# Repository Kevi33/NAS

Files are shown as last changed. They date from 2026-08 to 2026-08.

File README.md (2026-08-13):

# Parametric Raspberry Pi 5 NAS enclosure

This repository is an executable CadQuery project for a modular, FDM-printable mini-NAS. It is configured for two UGREEN 50422 / US222 drive enclosures, a Raspberry Pi 5 in a provisional GeeekPi metal case, a provisional UGREEN 25851 USB hub, a 120 mm front intake fan, and a measured 140 mm rear exhaust fan.

The build creates real solids rather than a rendering-only mock-up: individual STEP/STL print files, named assembled/exploded/checking STEP models, fit coupons, automated geometry reports, and PNG previews. The individual STL is the manufacturing source of truth: every placed printed instance is hard-gated to reach its final pose by rotation and translation only, never by an assembly-only reflection.

## Current configured envelope

- Body: **146.0 x 291.1 x 174.0 mm** (W x D x H)
- Installed depth including the external rear fan: **326.1 mm**
- External rear fan spacer: **10.0 mm**
- Height including 6 mm feet: **180.0 mm**
- Drive rear cable chamber: **60.0 mm**
- HDD guide clearance: **1.25 mm per guided side**
- HDD-to-HDD airflow gap: **12.0 mm**
- Production joint clearance: **0.20 mm per mating side**, calibrated from the printed P1S fit coupon
- HDD keeper clearance: **0.00 mm per side**, calibrated from the printed retention coupon and isolated from the panel/dovetail setting

The 291.1 mm depth is deliberate. Two 2.8 mm walls, a 25 mm fan, a 6.5 mm fan/drive gap, a 194 mm drive, and a 60 mm cable chamber cannot fit the initial 250-260 mm styling target without sacrificing cable bend space.

The configured printer is a **Bambu Lab P1S** with a physical 256 x 256 x 256 mm build volume. Validation uses a conservative 3 mm XY margin and a 250 mm usable Z limit. The enclosure remains intentionally split and modular; the larger printer profile does not merge or enlarge any enclosure part.

## Install and regenerate

CadQuery 2.6.1 with 64-bit CPython 3.12 is the tested toolchain.

```powershell
python -m venv .venv
.\.venv\Scripts\python.exe -m pip install -r requirements.txt
.\.venv\Scripts\python.exe build.py
```

To generate only the dedicated keeper-retention calibration model without touching enclosure exports, use:

```powershell
.\.venv\Scripts\python.exe build_keeper_retention_test.py
```

To regenerate only the two rear-fan printable parts plus affected assemblies and reports, while hash-protecting every unrelated export and slicer project, use:

```powershell
.\.venv\Scripts\python.exe build_rear_fan_update.py
```

On Linux/macOS, use `.venv/bin/python`. A good run ends with `BUILD RESULT: SUCCESS`; any source-solid, exported-mesh, STEP-reopen, print-bed, collision, cable-route, or service-path failure returns a non-zero exit code. The generator deletes only old files in its known output directories before rebuilding, so renamed artifacts cannot remain stale.

## Generated artifacts

```text
exports/
  individual/
    STL/                  # one printable source part per file
    STEP/
  assembly/
    NAS_Assembly.step
    NAS_Assembly.stl
    NAS_Assembly_preview.png
    NAS_Exploded.step
    NAS_Exploded.stl
    NAS_Exploded_preview.png
    NAS_Internal_Inspection.step
    NAS_Internal_Inspection.stl
    NAS_Internal_Inspection_preview.png
    NAS_Clearance_Check.step
  fit_tests/
    dovetail_fit_test.{stl,step}
    panel_key_fit_test.{stl,step}
    hdd_rail_fit_test.{stl,step}
    hdd_keeper_fit_test.{stl,step}
    hdd_keeper_retention_test.{stl,step}
    *_preview.png
reports/
  dimensions.md
  printability.md
  clearance_report.md
  hdd_keeper_retention_test_validation.md
REPRINT_REQUIRED.md         # compatibility/reprint decision after the production audit
```

The assembly, exploded, and cutaway `NAS_Internal_Inspection` STL files are disconnected inspection models containing printed and hardware solids. The cutaway omits the front, right side, and top shell modules to expose the internal relationships. Do not slice these inspection models as one print job. Use the individual STL files in the quantities listed in the dimension report.

## Parametric changes

Edit `config.py`, then rerun `build.py`; never hand-edit generated exports. Important uncertain dimensions are exposed centrally, including:

- `HDD_L`, `HDD_W`, `HDD_H`, clearances, and rear connector X/Z offsets
- `PI_CASE_L`, `PI_CASE_W`, `PI_CASE_H`, and Pi port/plug offsets
- `USB_HUB_L`, `USB_HUB_W`, `USB_HUB_H`, clearance, port offsets, and rear access envelope
- USB-B, DC, USB-A, Ethernet, USB-C, fan-adapter, and cable-bend envelopes
- `FIT_CLEARANCE`, the independent `HDD_KEEPER_CLEARANCE`, and all panel-key dimensions
- `PRINTER_MODEL`, `PRINT_BED_X`, `PRINT_BED_Y`, `PRINT_BED_Z`, `PRINT_USABLE_Z`, and `PRINT_BED_EDGE_MARGIN`

The case depth, module split, frame pockets, carrier locations, cable chamber, service sweeps, exports, and reports derive from these values. Because the real molded housings and plugs have not been measured, print the coupons and verify the report against caliper measurements before a full enclosure print.

## Mechanical layout and airflow

The 120 mm fan occupies the front/lower-middle region and blows rearward. Each HDD rests only on narrow edge rails, keeping the enclosure's underside heat-emission area open. Keyed side-panel ledges carry the split HDD cradles and the Pi tray; fixed front/rear base pedestals preserve a stable HDD support polygon while the right service panels are absent. Locator pockets prevent the carriers from wandering without permanently clamping the hardware.

The Pi sits above the drives and entirely ahead of the transverse structural C-frame. Air continues through the large frame opening into the rear cable chamber, then leaves through the centered 140 mm exhaust and passive base/side/top vents. The rear fan sits outside the original enclosure body on a shallow printed spacer/guard, preserving the fixed hub and cable chamber while keeping loose leads clear of the rotor.

The hub mounts vertically on a slotted rail carrier with a positive bottom stop, two strap stations, and two full-width M3 bearing bridges in the right-rear chamber. Only `right_side_rear` has the matching carrier holes. Its four provisional rear-facing USB plug envelopes pass through a chamfered rear service opening, including two explicitly modeled fan USB-adapter bodies. If physical measurement shows the real port face differs, change the hub/port parameters before printing.

The four side modules are physical production hands before export. `assembly.py` places them, both top modules, and the USB-hub carrier using proper rotations and translations only. An earlier left-rear print with two unused hub holes remains compatible; the current left-rear source simply omits those holes.

## Assembly and service order

1. Print all four calibration models first. Select the panel/joint clearance and confirm the real HDD nose in the rail slice.
2. Key `base_front` and `base_rear` into the structural `mid_frame`, then install the two left side modules. Leave the right service side open.
3. Join the lower front/rear skeletal cradle pair below its sliding surface, seat it on the left ledges and fixed base pedestals, install the lower HDD, and fit its load-shouldered keeper.
4. Repeat for the upper cradle and HDD. This lower-first order avoids trying to pass the lower drive through an installed upper tray.
5. Fasten the empty hub carrier to the right-rear module with M3 hardware and feed a removable strap through its slots. Slide both right modules into their capture rails and frame pockets, then fit the removable right frame spine.
6. Slide the front intake panel into its interrupted tongues. Insert the rear cable cover from behind in the forward direction. Install fans with proper fan screws or M4 through-bolts; do not rely on threads in a 2.8 mm panel.
7. Fit the fan guard, feet, and two floor cable clips. Lower the open Pi tray onto its four side ledges, then install and strap the Pi case.
8. Seat the USB hub against the carrier's bottom stop, secure its strap, and connect the low-voltage wiring. Keep every AC adapter outside the printed enclosure.
9. Fit `top_rear`, then the lift-off `top_service_lid` last to capture the side rails.

For Pi service, unplug it, remove only the front top service lid, and lift the case and tray vertically. For rear cable service, disconnect the 140 mm fan lead and pull the rear panel, external spacer/guard, and fan straight rearward (+Y); do not lift the panel against its interrupted tongues. Neither HDD needs to move.

For HDD service, remove both top modules, unplug and lift out the Pi and its tray, then disconnect all four hub device plugs and the hub host lead. The strapped hub may remain in its carrier. Remove both right side modules, the removable frame spine, and the selected drive's keeper; the selected HDD slides laterally to the right. The untouched loaded tray remains inside the support polygon formed by its left ledges and the fixed front/rear base pedestals.

## Fit coupons

- `dovetail_fit_test.stl`: five conventional long sliding-dovetail pairs at 0.20/0.25/0.30/0.35/0.40 mm per side.
- `panel_key_fit_test.stl`: the exact short planar key/pocket profile used by the production shell, at the same five clearances.
- `hdd_rail_fit_test.stl`: a 32 mm-deep full-width cradle slice for inserting the real UGREEN nose.
- `hdd_keeper_fit_test.stl`: the removable keeper and its supported rail socket.
- `hdd_keeper_retention_test.stl`: five production-faithful keeper/socket pairs at 0.00/0.05/0.10/0.15/0.20 mm keeper clearance, each with a broad rounded friction bead for light positive retention.

Labels give hundredths of a millimetre per mating side. On the keeper-retention coupon, match each loose keeper to the socket with the same label, orient its guide toward the open/outboard edge, and press it vertically down until both shoulders seat. After cooling, invert and lightly shake the pair, then confirm hand removal without tools. Use the smallest variant that seats by hand, does not rattle, and remains captured under gravity and light shaking.

The physically tested `00` variant is the current production keeper: its broad R1.0 friction bead provides light positive retention while remaining removable by hand. The HDD rail profile and the global panel/dovetail clearance remain independently calibrated and unchanged.

## Recommended FDM settings

- 0.4 mm nozzle; 0.20 mm layers
- 3-5 walls/perimeters; use 5 on frame, carrier, and joint-heavy parts
- 5 top and bottom layers
- 20-30% gyroid/cubic infill for panels; 30-40% for trays, frame, and keys
- PLA for cool prototypes; PETG preferred for joints, warm service, and fan-adjacent parts
- Use each part's preferred orientation in `reports/printability.md`; broad exterior faces go on the plate and internal ribs/open grooves face upward
- Generated supports: none in the preferred orientations
- Add a brim only if warping requires it; the largest production extent is 174 mm inside the conservative 250 mm usable envelope

## Automated validation

The build checks every production and fit-test model in its preferred orientation against the P1S profile: physical 256 x 256 x 256 mm, conservative validated envelope 250 x 250 x 250 mm. It does not use the larger bed to change the enclosure geometry or modular splits.

Every printable STL receives three independent hard gates in `reports/printability.md`: **MANIFOLD**, **PRINT BED**, and **NON-ZERO VOLUME**. The manifold audit checks connected regions, welded edge incidence, shared-edge winding, vertex-link topology, stored facet normals, degenerate and duplicate triangles, and the validity of the source BRep. Bounds, signed mesh volume, source/STEP volume identity, and the exact expected individual-STL inventory are also verified. Any failed gate makes `build.py` return a non-zero result.

`PRINTED_PART_ASSEMBLY_IDENTITY` separately reopens every actual production STL and registers every placed instance using only the 24 proper axis-aligned rotations plus translation. Bidirectional surface distance, volume, area, and dimensions must match the placed production source. A determinant -1-only match is reported as `REFLECTION REQUIRED` and is fatal. The gate also rejects identical left/right side exports and verifies the intended physical side-hand relationship.

The clearance suite checks printed-part self-intersections, hardware and cable volumes against printed parts, unrelated cross-system cable conflicts, intended endpoint continuity, positive fan/tray gaps, rear-wall route traversal, all 16 simultaneous end-panel tongue engagements, all 12 physical side/frame keys, right-only hub fastener ownership and bearing, keyed mechanical contacts, loaded-HDD support polygons after panel removal, and sampled HDD/Pi/right-panel/right-spine/rear-cover service sweeps with only explicitly removable or unplugged items excluded. Details are in the three Markdown reports.

## Measurement cautions

The drive envelope and connector types follow the supplied brief. Public US222 documentation identifies USB 3.0 Type-B, a 5.5 mm 12 V DC input, a power control, and underside heat-emission openings. Reference pages: [US222 manual mirror](https://device.report/manual/6657570), [UGREEN Singapore product page](https://ugreen.com.sg/products/ugreen-usb-3-0-3-5inch-hard-drive-box-uk-plug), and [UGREEN 25851 page](https://www.ugreen.com/en-au/products/au-25851).

These sources do not replace caliper checks. Connector coordinates, plug overmolds, rubber feet, molded tapers, exact GeeekPi port locations, the hub's true port face, and fan-adapter bodies remain provisional. Treat the first build as an engineering prototype.

Verify each fan's nameplate voltage and current before powering it. Many PC fans are 12 V; a USB fan adapter must provide the fan's required voltage/current rather than merely adapting the connector shape.

## Source map

- `src/base.py`, `front.py`, `rear.py`, `left_panel.py`, `right_panel.py`, `top.py`: shell modules
- `src/mid_frame.py`: structural split hoop and removable HDD service spine
- `src/hdd_tray.py`, `pi_tray.py`, `usb_hub_mount.py`: removable hardware carriers
- `src/hardware_dummies.py`, `fans.py`: non-printable hardware, connector, cable, airflow, and service references
- `src/assembly.py`: exact placements, quantities, colors, and exploded transforms
- `src/validation.py`: source/export/bed/mesh/STEP/collision/service checks and reports
- `src/fit_tests.py`: calibration prints
- `build.py`: one-command artifact generator

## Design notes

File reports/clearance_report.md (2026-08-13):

# Clearance and collision report

Summary: **154/154 checks passed**.

Boolean intersections larger than 0.10 mm³ are failures except for the two explicitly bounded, coupon-calibrated HDD keeper friction beads. Zero-volume support contact is intentional.

- **PASS** — Printed assembly self-collision: No printed-part self-intersections.
- **PASS** — Calibrated keeper retention: hdd_keeper_lower / hdd_tray_lower_front: Elastic bead/socket interference 0.205 mm³; required 0.15–0.30 mm³; localized bounds 3.600 x 0.100 x 0.872 mm.
- **PASS** — Calibrated keeper retention: hdd_keeper_upper / hdd_tray_upper_front: Elastic bead/socket interference 0.205 mm³; required 0.15–0.30 mm³; localized bounds 3.600 x 0.100 x 0.872 mm.
- **PASS** — HDD2 lower enclosure clearance: No forbidden intersections.
- **PASS** — HDD1 upper enclosure clearance: No forbidden intersections.
- **PASS** — Raspberry Pi case clearance: No forbidden intersections.
- **PASS** — USB hub clearance: No forbidden intersections.
- **PASS** — 120 mm fan clearance: No forbidden intersections.
- **PASS** — 140 mm fan clearance: No forbidden intersections.
- **PASS** — HDD lower USB B plug: No forbidden intersections.
- **PASS** — HDD lower DC plug: No forbidden intersections.
- **PASS** — HDD upper USB B plug: No forbidden intersections.
- **PASS** — HDD upper DC plug: No forbidden intersections.
- **PASS** — Pi Ethernet plug: No forbidden intersections.
- **PASS** — Pi USB C plug: No forbidden intersections.
- **PASS** — Pi USB A plug: No forbidden intersections.
- **PASS** — HDD lower USB B bend zone: No forbidden intersections.
- **PASS** — HDD lower DC bend zone: No forbidden intersections.
- **PASS** — HDD lower switch access: No forbidden intersections.
- **PASS** — HDD upper USB B bend zone: No forbidden intersections.
- **PASS** — HDD upper DC bend zone: No forbidden intersections.
- **PASS** — HDD upper switch access: No forbidden intersections.
- **PASS** — Pi port and route clearance: No forbidden intersections.
- **PASS** — USB hub plug clearance: No forbidden intersections.
- **PASS** — USB hub front fan USB adapter: No forbidden intersections.
- **PASS** — USB hub rear fan USB adapter: No forbidden intersections.
- **PASS** — USB hub host cable bend: No forbidden intersections.
- **PASS** — HDD lower rear exit route: No forbidden intersections.
- **PASS** — HDD upper rear exit route: No forbidden intersections.
- **PASS** — front fan wire route: No forbidden intersections.
- **PASS** — rear fan wire route: No forbidden intersections.
- **PASS** — USB hub host cable route: No forbidden intersections.
- **PASS** — Rear grille bars terminate into both structural lands: 6 bars; each has two end attachments at least 0.80 mm deep, zero service-opening overlap, at least 0.91 mm service gap, and 4.00 mm width.
- **PASS** — Rear grille and fan guard connected solids: Rear panel 1 solid(s); fan guard 1 solid(s).
- **PASS** — Rear panel and fan guard configured envelopes: Panel 143.20 x 168.40 x 2.80 mm; guard 140.00 x 140.00 x 10.00 mm.
- **PASS** — Rear cable and service openings remain unobstructed: Residual printed volume inside all five opening cutters: 0.000 mm³.
- **PASS** — Rear grille nominal airflow open area: Vertical-bar pattern is 78.6% open within the circular aperture; required 75.0%.
- **PASS** — Rear-stack separation: 140 mm rear fan / USB hub body: Intersection 0.000 mm³; minimum distance 42.800 mm.
- **PASS** — Rear-stack separation: 140 mm rear fan / USB hub plug field: Intersection 0.000 mm³; minimum distance 4.800 mm.
- **PASS** — Rear-stack separation: 140 mm rear fan / Raspberry Pi cable route: Intersection 0.000 mm³; minimum distance 9.000 mm.
- **PASS** — Rear-stack separation: 140 mm rear fan / lower HDD USB-B bend: Intersection 0.000 mm³; minimum distance 18.800 mm.
- **PASS** — Rear-stack separation: 140 mm rear fan / lower HDD DC bend: Intersection 0.000 mm³; minimum distance 24.800 mm.
- **PASS** — Rear-stack separation: 140 mm rear fan / lower HDD rear route: Intersection 0.000 mm³; minimum distance 9.552 mm.
- **PASS** — Rear-stack separation: 140 mm rear fan / upper HDD USB-B bend: Intersection 0.000 mm³; minimum distance 20.201 mm.
- **PASS** — Rear-stack separation: 140 mm rear fan / upper HDD DC bend: Intersection 0.000 mm³; minimum distance 27.701 mm.
- **PASS** — Rear-stack separation: 140 mm rear fan / upper HDD rear route: Intersection 0.000 mm³; minimum distance 9.552 mm.
- **PASS** — Rear-stack separation: 140 mm rear fan / top rear panel: Intersection 0.000 mm³; minimum distance 10.198 mm.
- **PASS** — Rear-stack separation: 140 mm rear fan / right rear side module: Intersection 0.000 mm³; minimum distance 10.002 mm.
- **PASS** — Rear-stack separation: rear fan spacer/guard / USB hub body: Intersection 0.000 mm³; minimum distance 32.800 mm.
- **PASS** — Rear-stack separation: rear fan spacer/guard / USB hub plug field: Intersection 0.000 mm³; minimum distance 2.408 mm.
- **PASS** — Rear-stack separation: rear fan spacer/guard / Raspberry Pi cable route: Intersection 0.000 mm³; minimum distance 0.500 mm.
- **PASS** — Rear-stack separation: rear fan spacer/guard / lower HDD USB-B bend: Intersection 0.000 mm³; minimum distance 8.800 mm.
- **PASS** — Rear-stack separation: rear fan spacer/guard / lower HDD DC bend: Intersection 0.000 mm³; minimum distance 14.800 mm.
- **PASS** — Rear-stack separation: rear fan spacer/guard / lower HDD rear route: Intersection 0.000 mm³; minimum distance 3.200 mm.
- **PASS** — Rear-stack separation: rear fan spacer/guard / upper HDD USB-B bend: Intersection 0.000 mm³; minimum distance 18.472 mm.
- **PASS** — Rear-stack separation: rear fan spacer/guard / upper HDD DC bend: Intersection 0.000 mm³; minimum distance 25.652 mm.
- **PASS** — Rear-stack separation: rear fan spacer/guard / upper HDD rear route: Intersection 0.000 mm³; minimum distance 2.800 mm.
- **PASS** — Rear-stack separation: rear fan spacer/guard / top rear panel: Intersection 0.000 mm³; minimum distance 2.000 mm.
- **PASS** — Rear-stack separation: rear fan spacer/guard / right rear side module: Intersection 0.000 mm³; minimum distance 0.200 mm.
- **PASS** — Hardware separation: HDD_lower / HDD_upper: Intersection volume 0.000 mm³.
- **PASS** — Hardware separation: HDD_lower / Pi_case: Intersection volume 0.000 mm³.
- **PASS** — Hardware separation: HDD_lower / USB_hub: Intersection volume 0.000 mm³.
- **PASS** — Hardware separation: HDD_lower / fan_120: Intersection volume 0.000 mm³.
- **PASS** — Hardware separation: HDD_lower / fan_140: Intersection volume 0.000 mm³.
- **PASS** — Hardware separation: HDD_upper / Pi_case: Intersection volume 0.000 mm³.
- **PASS** — Hardware separation: HDD_upper / USB_hub: Intersection volume 0.000 mm³.
- **PASS** — Hardware separation: HDD_upper / fan_120: Intersection volume 0.000 mm³.
- **PASS** — Hardware separation: HDD_upper / fan_140: Intersection volume 0.000 mm³.
- **PASS** — Hardware separation: Pi_case / USB_hub: Intersection volume 0.000 mm³.
- **PASS** — Hardware separation: Pi_case / fan_120: Intersection volume 0.000 mm³.
- **PASS** — Hardware separation: Pi_case / fan_140: Intersection volume 0.000 mm³.
- **PASS** — Hardware separation: USB_hub / fan_120: Intersection volume 0.000 mm³.
- **PASS** — Hardware separation: USB_hub / fan_140: Intersection volume 0.000 mm³.
- **PASS** — Hardware separation: fan_120 / fan_140: Intersection volume 0.000 mm³.
- **PASS** — Cross-system connector and cable separation: 332 unrelated cross-system pairs checked; 5 declared electrical connection pairs handled separately.
- **PASS** — Cable continuity: Lower HDD USB-B plug to bend: Endpoint distance 0.000 mm.
- **PASS** — Cable continuity: Lower HDD USB-B bend to exit: Endpoint distance 0.000 mm.
- **PASS** — Cable continuity: Lower HDD DC plug to bend: Endpoint distance 0.000 mm.
- **PASS** — Cable continuity: Lower HDD DC bend to exit: Endpoint distance 0.000 mm.
- **PASS** — Cable continuity: Upper HDD USB-B plug to bend: Endpoint distance 0.000 mm.
- **PASS** — Cable continuity: Upper HDD USB-B bend to exit: Endpoint distance 0.000 mm.
- **PASS** — Cable continuity: Upper HDD DC plug to bend: Endpoint distance 0.000 mm.
- **PASS** — Cable continuity: Upper HDD DC bend to exit: Endpoint distance 0.000 mm.
- **PASS** — Cable continuity: Pi Ethernet plug to routed field: Endpoint distance 0.000 mm.
- **PASS** — Cable continuity: Pi USB-C plug to routed field: Endpoint distance 0.000 mm.
- **PASS** — Cable continuity: Pi USB-A plug to routed field: Endpoint distance 0.000 mm.
- **PASS** — Cable continuity: Hub body to host bend: Endpoint distance 0.000 mm.
- **PASS** — Cable continuity: Hub host bend to route: Endpoint distance 0.000 mm.
- **PASS** — Cable continuity: Hub host route to Pi field: Endpoint distance 0.000 mm.
- **PASS** — Cable continuity: Front fan to wire route: Endpoint distance 0.000 mm.
- **PASS** — Cable continuity: Front fan route to USB adapter: Endpoint distance 0.000 mm.
- **PASS** — Cable continuity: Front fan adapter to hub: Endpoint distance 0.000 mm.
- **PASS** — Cable continuity: Rear fan to wire route: Endpoint distance 0.000 mm.
- **PASS** — Cable continuity: Rear fan route to USB adapter: Endpoint distance 0.000 mm.
- **PASS** — Cable continuity: Rear fan adapter to hub: Endpoint distance 0.000 mm.
- **PASS** — HDD lower service sweep: No forbidden intersections.
- **PASS** — HDD upper service sweep: No forbidden intersections.
- **PASS** — Pi vertical service sweep: No forbidden intersections.
- **PASS** — Mechanical contact: hdd_tray_lower_front / left_side_front: Minimum surface distance 0.000 mm.
- **PASS** — Mechanical contact: hdd_tray_lower_front / right_side_front: Minimum surface distance 0.000 mm.
- **PASS** — Mechanical contact: hdd_tray_lower_front / base_front: Minimum surface distance 0.000 mm.
- **PASS** — Mechanical contact: hdd_tray_lower_rear / left_side_rear: Minimum surface distance 0.000 mm.
- **PASS** — Mechanical contact: hdd_tray_lower_rear / right_side_rear: Minimum surface distance 0.000 mm.
- **PASS** — Mechanical contact: hdd_tray_lower_rear / base_rear: Minimum surface distance 0.000 mm.
- **PASS** — Mechanical contact: hdd_tray_upper_front / left_side_front: Minimum surface distance 0.000 mm.
- **PASS** — Mechanical contact: hdd_tray_upper_front / right_side_front: Minimum surface distance 0.000 mm.
- **PASS** — Mechanical contact: hdd_tray_upper_front / base_front: Minimum surface distance 0.000 mm.
- **PASS** — Mechanical contact: hdd_tray_upper_rear / left_side_rear: Minimum surface distance 0.000 mm.
- **PASS** — Mechanical contact: hdd_tray_upper_rear / right_side_rear: Minimum surface distance 0.000 mm.
- **PASS** — Mechanical contact: hdd_tray_upper_rear / base_rear: Minimum surface distance 0.000 mm.
- **PASS** — Mechanical contact: hdd_keeper_lower / hdd_tray_lower_front: Minimum surface distance 0.000 mm.
- **PASS** — Mechanical contact: hdd_keeper_upper / hdd_tray_upper_front: Minimum surface distance 0.000 mm.
- **PASS** — Mechanical contact: pi_tray / left_side_front: Minimum surface distance 0.000 mm.
- **PASS** — Mechanical contact: pi_tray / right_side_front: Minimum surface distance 0.000 mm.
- **PASS** — Mechanical contact: usb_hub_mount / right_side_rear: Minimum surface distance 0.000 mm.
- **PASS** — Mechanical contact: cable_clip_1 / base_rear: Minimum surface distance 0.000 mm.
- **PASS** — Mechanical contact: cable_clip_2 / base_rear: Minimum surface distance 0.000 mm.
- **PASS** — Mechanical contact: foot_1 / base_front: Minimum surface distance 0.000 mm.
- **PASS** — Mechanical contact: foot_2 / base_front: Minimum surface distance 0.000 mm.
- **PASS** — Mechanical contact: foot_3 / base_rear: Minimum surface distance 0.000 mm.
- **PASS** — Mechanical contact: foot_4 / base_rear: Minimum surface distance 0.000 mm.
- **PASS** — Simultaneous front/rear panel engagement with both side hands: All 16 interrupted tongue/groove interfaces are present and clear by 0.20 mm.
- **PASS** — Physical side-to-mid-frame key engagement: All 12 physical side tabs are contained in their exported owner and enter the intended frame receiver within 0.20 mm.
- **PASS** — Right-only USB-hub fastener ownership and carrier bearing: Both M3 axes pass through the right rear and slotted carrier bridges with positive surrounding bearing material; the left rear retains solid wall.
- **PASS** — Mechanical contact: USB hub bottom retention: Minimum surface distance 0.000 mm.
- **PASS** — Mechanical contact: 120 mm fan panel seating: Minimum surface distance 0.000 mm.
- **PASS** — Mechanical contact: Rear spacer to panel seating: Minimum surface distance 0.000 mm.
- **PASS** — Mechanical contact: 140 mm fan to spacer seating: Minimum surface distance 0.000 mm.
- **PASS** — HDD lower post-removal support polygon: HDD center (73.0, 131.3); fixed/left support polygon ((12.35, 60.0), (133.65, 31.549999999999997), (133.65, 231.05), (12.35, 205.0)).
- **PASS** — HDD upper post-removal support polygon: HDD center (73.0, 131.3); fixed/left support polygon ((12.35, 60.0), (133.65, 31.549999999999997), (133.65, 231.05), (12.35, 205.0)).
- **PASS** — Right-front side-panel removal after Pi tray removal: 67 rigid-body positions checked through (1.0, 0.0, 0.0) x 20.0 mm.
- **PASS** — Right mid-frame spine removal after both right panels: 67 rigid-body positions checked through (1.0, 0.0, 0.0) x 20.0 mm.
- **PASS** — Right-rear side-panel and unplugged hub-carrier removal: 67 rigid-body positions checked through (1.0, 0.0, 0.0) x 20.0 mm.
- **PASS** — Rear cable-cover, fan, and guard rearward removal: 80 rigid-body positions checked through (0.0, 1.0, 0.0) x 80.0 mm.
- **PASS** — Rear-wall traversal: Pi_port_and_route_clearance: Route reaches Y=292.10 mm past rear wall Y=291.10 mm.
- **PASS** — Rear-wall traversal: HDD_lower_rear_exit_route: Route reaches Y=292.10 mm past rear wall Y=291.10 mm.
- **PASS** — Rear-wall traversal: HDD_upper_rear_exit_route: Route reaches Y=292.10 mm past rear wall Y=291.10 mm.
- **PASS** — Rear-wall traversal: USB_hub_plug_clearance: Route reaches Y=296.30 mm past rear wall Y=291.10 mm.
- **PASS** — Rear-wall traversal: rear_fan_wire_route: Route reaches Y=301.10 mm past rear wall Y=291.10 mm.
- **PASS** — HDD-to-HDD airflow gap: Actual 12.00 mm; required 12.00 mm.
- **PASS** — HDD rear cable chamber depth: Actual 60.00 mm; required 60.00 mm.
- **PASS** — HDD left rail guide clearance: Actual 1.25 mm; configured 1.25 mm.
- **PASS** — Pi clear of structural mid-frame: Horizontal service gap 5.25 mm.
- **PASS** — Front fan to HDD nose gap: Actual 6.50 mm.
- **PASS** — Front fan to tray clearance: Actual 2.25 mm.
- **PASS** — Rear fan top clearance: Actual 2.00 mm.
- **PASS** — Provisional USB hub plug field to rear fan guard clearance: Actual 2.41 mm; required 1.50 mm.
- **PASS** — Pi route to rear fan guard clearance: Actual 0.50 mm; required 0.20 mm.
- **PASS** — Lower HDD route to rear fan guard clearance: Actual 3.20 mm; required 0.20 mm.
- **PASS** — Upper HDD route to rear fan guard clearance: Actual 2.80 mm; required 0.20 mm.
- **PASS** — 140 mm rear fan horizontal centering: Centering error 0.0000 mm; fan X=3.00 mm.
- **PASS** — External rear fan spacer depth: Panel-to-fan spacing 10.00 mm.
- **PASS** — Rear fan opening structural lands: Side/top/low-slot webs 3.70/5.50/3.50 mm; required 2.80 mm.
- **PASS** — Fixed HDD service posts clear drive body: Front/rear body gaps 1.25/1.25 mm; required 1.25 mm.

## Service-path assumptions

- HDD sweep checks remove both right shell modules, the selected keeper, and removable right mid-frame spine.
- Before right-side withdrawal, the Pi/tray is removed and every hub device/host lead is unplugged; the strapped hub moves with its carrier.
- The untouched loaded HDD remains inside the fixed-pedestal/left-ledge support polygon.
- Pi sweep checks remove only the top service lid.
- Rear cable-cover service is sampled as a rigid +Y pull of panel, fan, and guard after the fan lead is unplugged.
- Connector/bend coordinates remain provisional until the real hardware is measured.

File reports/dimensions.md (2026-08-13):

# Dimension report

Generated directly from the current `config.py` and CadQuery bounding boxes.

## Final configured dimensions

- Width: **146.00 mm**
- Unchanged enclosure-body depth: **291.10 mm**
- Installed depth including external rear fan: **326.10 mm**
- External rear spacer depth: **10.00 mm**
- Body height: **174.00 mm**
- Overall height including feet: **180.00 mm**

## Printer validation profile

- Printer: **Bambu Lab P1S**
- Physical build volume: **256 x 256 x 256 mm**
- Conservative validated envelope: **250 x 250 x 250 mm**
- The enclosure geometry and modular panel splits are unchanged by the larger printer profile.

> The depth intentionally exceeds the 250–260 mm design target. A 194.0 mm drive, 25.0 mm fan, 6.5 mm fan gap, 60.0 mm cable chamber, and two walls require 291.10 mm.

## Printable component bounding boxes

| Part | Qty | X | Y | Z | All STL gates |
|---|---:|---:|---:|---:|:---:|
| `base_front` | 1 | 146.00 | 145.55 | 60.00 | PASS |
| `base_rear` | 1 | 146.00 | 145.55 | 60.00 | PASS |
| `foot` | 4 | 16.00 | 16.00 | 6.00 | PASS |
| `front_panel` | 1 | 143.20 | 168.40 | 2.80 | PASS |
| `rear_panel` | 1 | 143.20 | 168.40 | 2.80 | PASS |
| `rear_fan_guard` | 1 | 140.00 | 140.00 | 10.00 | PASS |
| `left_side_front` | 1 | 145.55 | 168.40 | 13.85 | PASS |
| `left_side_rear` | 1 | 145.55 | 168.40 | 13.85 | PASS |
| `right_side_front` | 1 | 145.55 | 168.40 | 13.85 | PASS |
| `right_side_rear` | 1 | 145.55 | 168.40 | 13.85 | PASS |
| `top_service_lid` | 1 | 146.00 | 145.55 | 6.80 | PASS |
| `top_rear` | 1 | 146.00 | 145.55 | 6.80 | PASS |
| `mid_frame` | 1 | 146.00 | 174.00 | 8.00 | PASS |
| `mid_frame_right_spine` | 1 | 8.00 | 164.00 | 8.00 | PASS |
| `hdd_tray_front` | 2 | 124.30 | 107.25 | 9.00 | PASS |
| `hdd_tray_rear` | 2 | 124.30 | 101.25 | 9.00 | PASS |
| `hdd_keeper` | 2 | 8.00 | 16.00 | 9.00 | PASS |
| `pi_tray` | 1 | 128.00 | 95.00 | 8.00 | PASS |
| `usb_hub_mount` | 1 | 19.00 | 119.00 | 7.00 | PASS |
| `cable_clip` | 2 | 12.80 | 10.00 | 15.20 | PASS |
| `dovetail_fit_test` | 1 | 154.00 | 66.00 | 6.50 | PASS |
| `panel_key_fit_test` | 1 | 152.00 | 50.00 | 3.30 | PASS |
| `hdd_rail_fit_test` | 1 | 124.30 | 32.00 | 9.00 | PASS |
| `hdd_keeper_fit_test` | 1 | 26.40 | 32.00 | 9.00 | PASS |
| `hdd_keeper_retention_test` | 1 | 122.20 | 32.00 | 9.00 | PASS |

Largest single preferred-orientation extent: **174.00 mm** on `mid_frame`.

## Hardware placement and clearances

- HDD #2 (lower) min corner: X 14.50, Y 34.30, Z 13.00
- HDD #1 (upper) min corner: X 14.50, Y 34.30, Z 63.00
- HDD-to-HDD gap: **12.00 mm**
- HDD guide clearance: **1.25 mm per guided side**
- HDD rear cable clearance: **60.00 mm**
- Pi min corner: X 40.00, Y 44.30, Z 113.00
- Pi side clearance to inner shell: 37.20 mm left / 37.20 mm right
- Pi top clearance: 18.20 mm
- Pi-to-mid-frame service gap: 5.25 mm
- USB hub rail-envelope clearance: 1.50 mm per side; mounting slots permit vertical adjustment
- 120 mm fan min corner: X 13.00, Y 2.80, Z 27.00
- 140 mm fan min corner: X 3.00, Y 301.10, Z 29.20
- Panel thickness: **2.80 mm**
- Sliding fit clearance: **0.20 mm per mating side**
- HDD keeper clearance: **0.00 mm per mating side**
- Mid-frame: Y 141.55 to 149.55 mm

## Provisional dimensions to measure

The UGREEN rear connector X/Z coordinates, molded plug overmolds, Pi case port locations, USB hub envelope, rubber feet, tapers, and vent locations are parameterized assumptions. Check them with calipers and edit `config.py` before a full print.

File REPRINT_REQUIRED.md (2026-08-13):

# Production reprint decision

This decision applies to parts printed before the 2026-08-13 full production-export audit. The authoritative manufacturing files are the regenerated files in `exports/individual/STL/`; preserved slicer-project (`.3mf`) files are not regenerated or covered by the production identity gate.

## Must reprint

| Part | Decision | Reason |
|---|---|---|
| `right_side_front` | **REPRINT REQUIRED** | The old STL was the left-hand part. It reached the intended right-side assembly pose only through a forbidden reflection in `assembly.py`. The new STL contains the physical right hand. |
| `right_side_rear` | **REPRINT REQUIRED** | The old STL was not the physical right hand. The new STL contains the right-hand ledges/keys plus the two USB-hub carrier holes. |
| `usb_hub_mount` | **REPRINT REQUIRED** | The audit found both former M3 slots entirely inside the open center window, leaving no carrier bearing material at either screw. The corrected carrier adds two compact, slotted back bridges without moving the hub or fastener axes. |

## Previously printed parts that remain valid

| Part | Decision | Compatibility note |
|---|---|---|
| `base_front` | Valid | Production geometry unchanged. |
| `base_rear` | Valid | Production geometry unchanged. |
| `front_panel` | Valid | 120 mm intake geometry unchanged. |
| `rear_panel` | Valid | Current 140 mm production geometry unchanged by this audit. |
| `rear_fan_guard` | Valid if it is the current 140 mm part | Current production geometry remains 140 x 140 x 10 mm. See the stale-3MF warning below. |
| `left_side_front` | Valid | Production geometry unchanged. |
| `left_side_rear` | Valid, including the earlier holed print | The new source omits two unused hub holes. The earlier holed left panel is a strict material subset with unchanged mating envelopes, keys, and ledges, so it remains compatible. |
| `top_service_lid` | Valid | STL geometry unchanged; assembly placement now expresses the same pose with a physical 180-degree rotation. |
| `top_rear` | Valid | STL geometry unchanged; assembly placement now expresses the same pose with a physical 180-degree rotation. |
| `mid_frame` | Valid | Production geometry unchanged. |
| `mid_frame_right_spine` | Valid | Production geometry unchanged. |
| `hdd_tray_front` | Valid | Rail and tray geometry unchanged. |
| `hdd_tray_rear` | Valid | Rail and tray geometry unchanged. |
| `hdd_keeper` | Valid | Calibrated 0.00 mm keeper geometry unchanged. |
| `pi_tray` | Valid | Production geometry unchanged. |
| `cable_clip` | Valid | Production geometry unchanged. |
| `foot` | Valid | Production geometry unchanged. |

## Preserved slicer-project warning

- `exports/individual/STL/rear_fan_guard.3mf` contains the obsolete 80 x 80 x 8 mm guard, not the current 140 x 140 x 10 mm production part. A guard printed from that file must be reprinted from `rear_fan_guard.stl`.
- `exports/individual/STL/usb_hub_mount.3mf` contains the old carrier without usable fastener bridges. Do not print it; use the regenerated `usb_hub_mount.stl`.
- `exports/individual/STL/hdd_tray_front.3mf` is a multi-object slicer project that also embeds the old hub-carrier mesh. It is not an authoritative single-part export.

In total, 3 of the 20 production part types require replacement; the other 17 remain compatible under the conditions above.

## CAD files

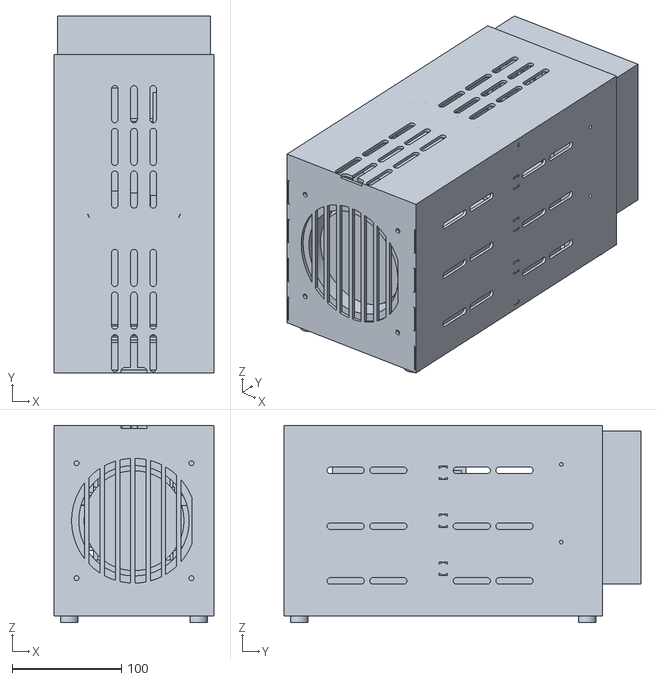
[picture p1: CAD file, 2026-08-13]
exports/assembly/NAS_Assembly.stl
146.0 x 326.1 x 180.0

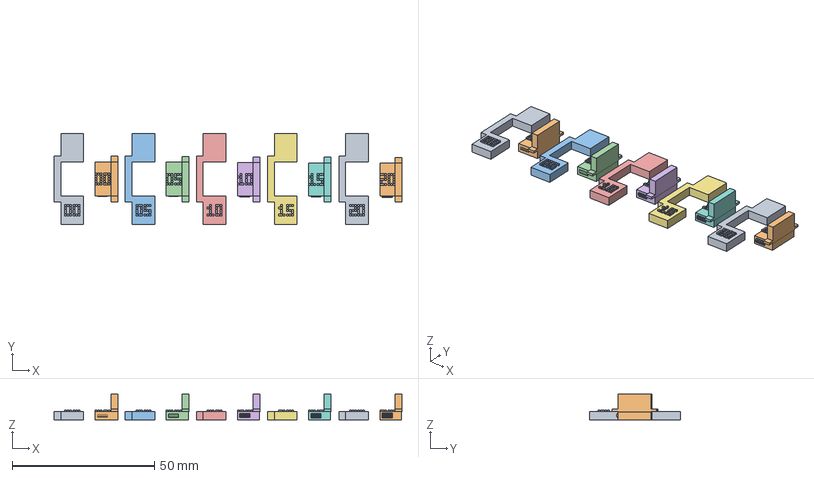
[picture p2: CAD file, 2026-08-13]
exports/fit_tests/hdd_keeper_retention_test.step
122.2 x 32.0 x 9.00 mm

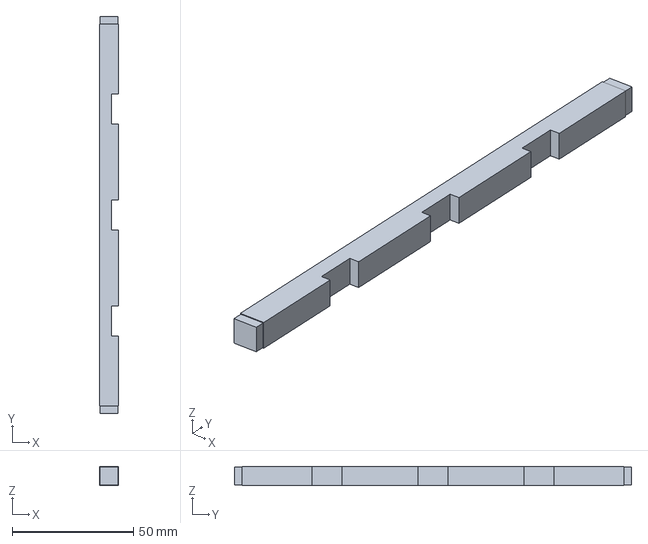
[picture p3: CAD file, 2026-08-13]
exports/individual/STEP/mid_frame_right_spine.step
8.00 x 164.0 x 8.00 mm

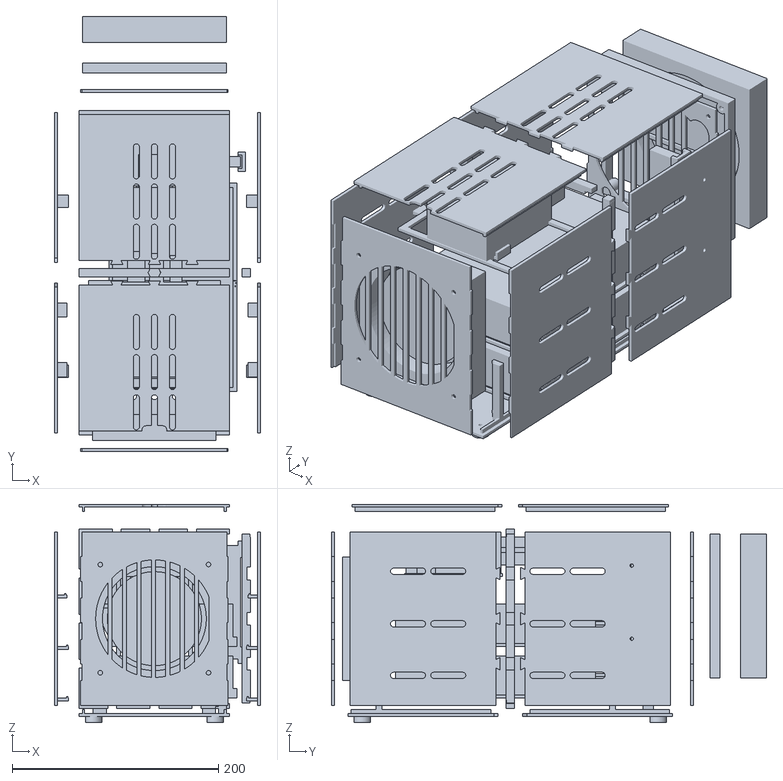
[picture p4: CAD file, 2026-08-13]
exports/assembly/NAS_Exploded.stl
200.0 x 422.1 x 212.0

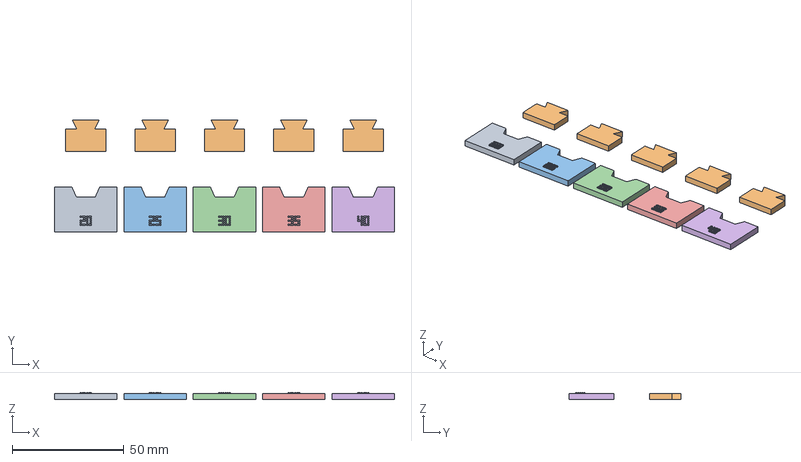
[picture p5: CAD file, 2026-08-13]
exports/fit_tests/panel_key_fit_test.step
152.0 x 50.0 x 3.30 mm

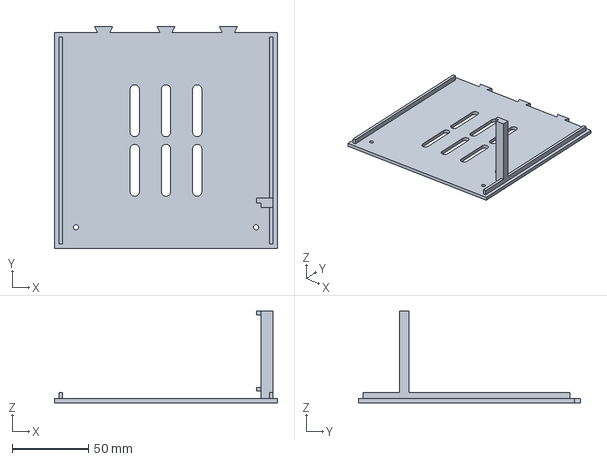
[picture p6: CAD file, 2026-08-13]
exports/individual/STEP/base_front.step
146.0 x 145.6 x 60.0 mm

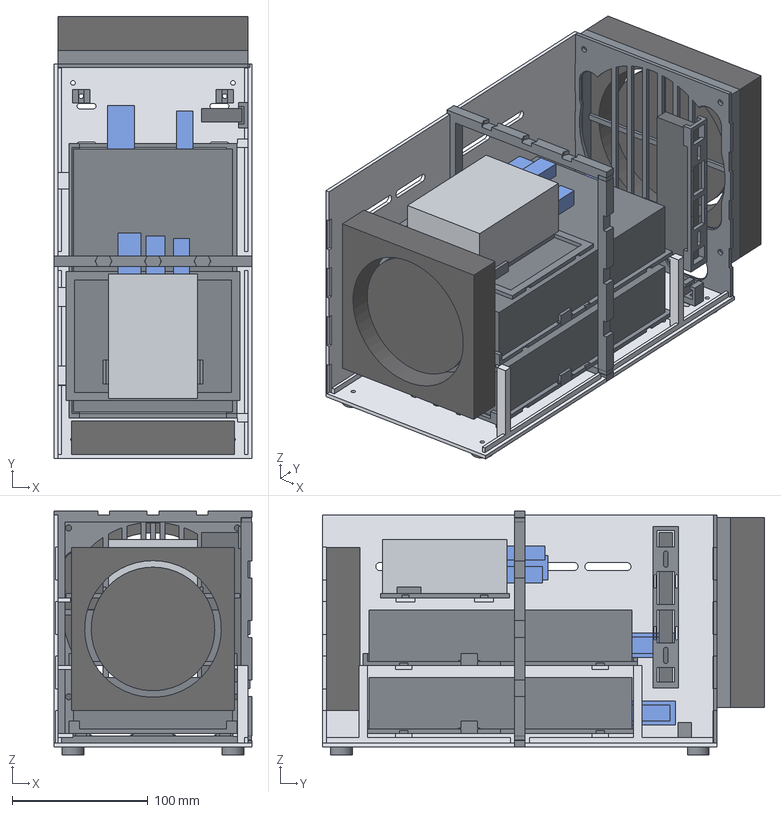
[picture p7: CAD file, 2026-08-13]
exports/assembly/NAS_Internal_Inspection.step
146.0 x 326.1 x 180.0 mm
base_front
base_rear
left_side_front
left_side_rear
rear_panel
mid_frame
mid_frame_right_spine
hdd_tray_lower_front
hdd_tray_lower_rear
hdd_keeper_lower
hdd_tray_upper_front
hdd_tray_upper_rear
hdd_keeper_upper
pi_tray
usb_hub_mount
rear_fan_guard
foot_1
foot_2
foot_3
foot_4
cable_clip_1
cable_clip_2
HDD_lower
HDD_upper
Pi_case
USB_hub
fan_120
fan_140
HDD_lower_USB_B_plug
HDD_lower_DC_plug
HDD_upper_USB_B_plug
HDD_upper_DC_plug
Pi_Ethernet_plug
Pi_USB_C_plug
Pi_USB_A_plug

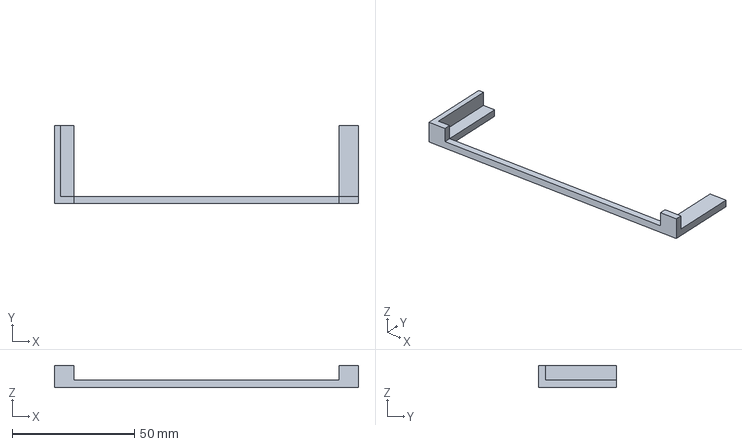
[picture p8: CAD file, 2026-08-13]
exports/fit_tests/hdd_rail_fit_test.step
124.3 x 32.0 x 9.00 mm

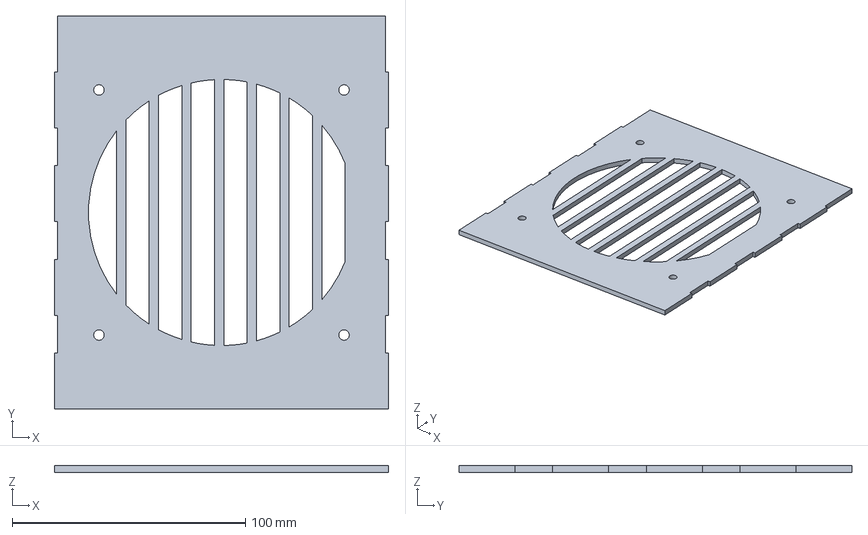
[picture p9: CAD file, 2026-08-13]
exports/individual/STEP/front_panel.step
143.2 x 168.4 x 2.80 mm

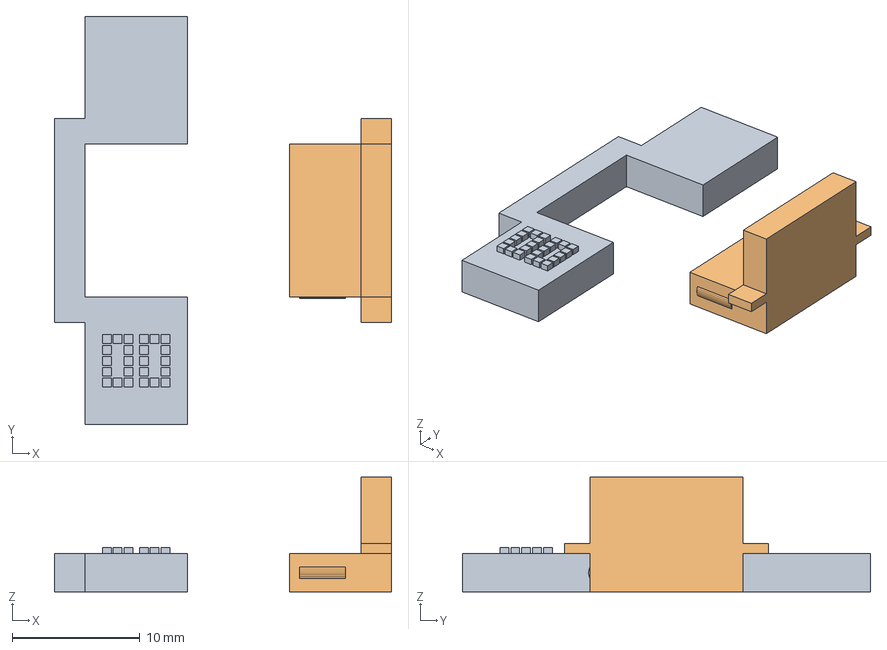
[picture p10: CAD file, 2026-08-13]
exports/fit_tests/hdd_keeper_fit_test.step
26.4 x 32.0 x 9.00 mm

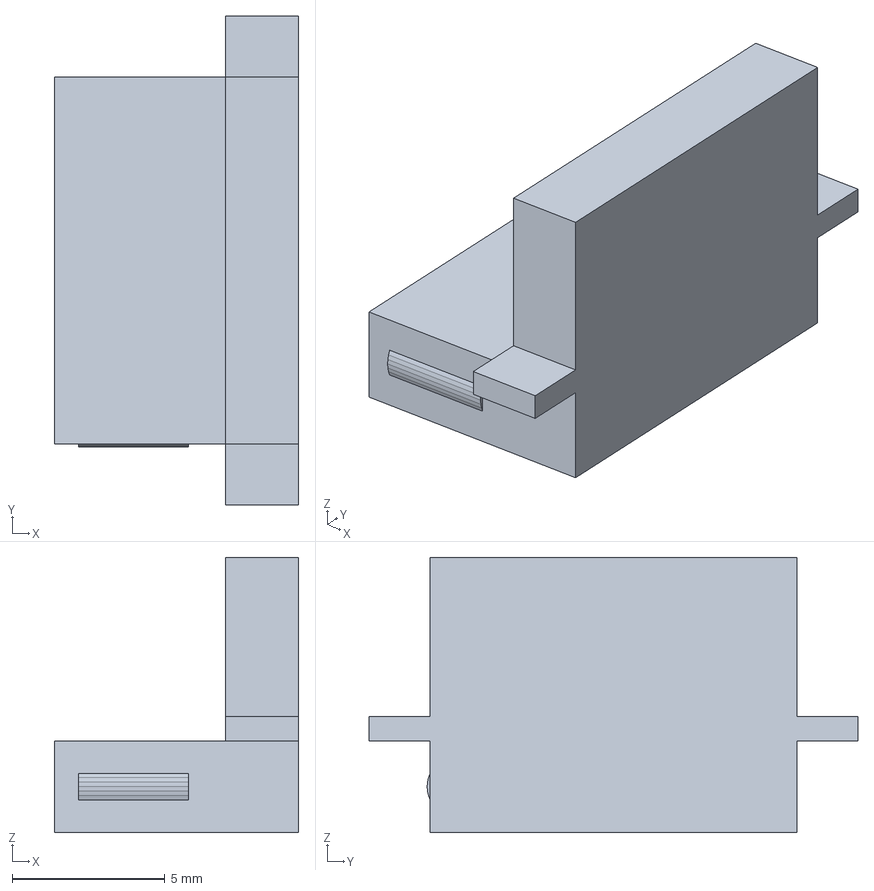
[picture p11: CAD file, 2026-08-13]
exports/individual/STEP/hdd_keeper.step
8.00 x 16.0 x 9.00 mm

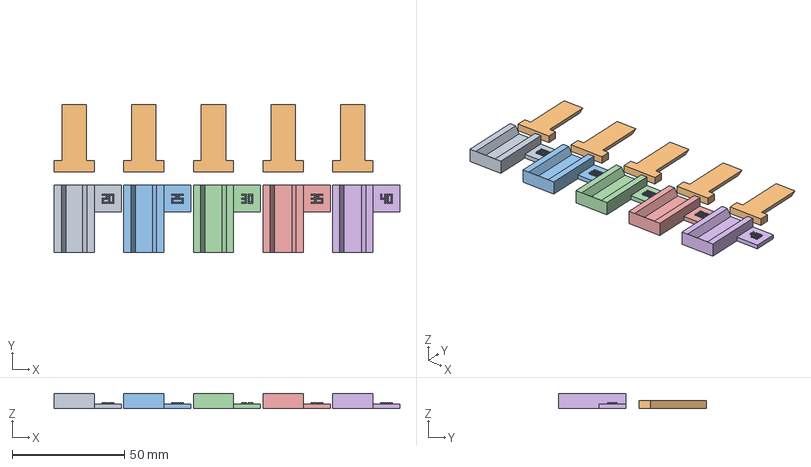
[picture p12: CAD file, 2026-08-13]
exports/fit_tests/dovetail_fit_test.step
154.0 x 66.0 x 6.50 mm

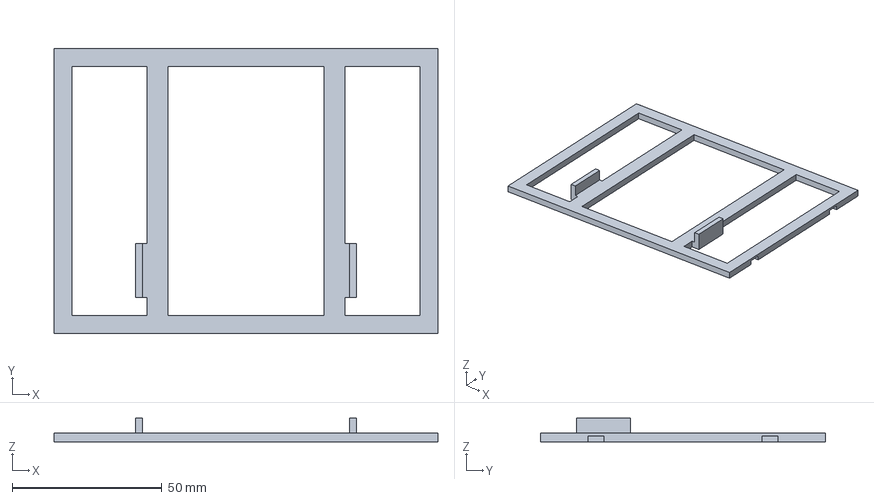
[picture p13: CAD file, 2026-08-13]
exports/individual/STEP/pi_tray.step
128.0 x 95.0 x 8.00 mm

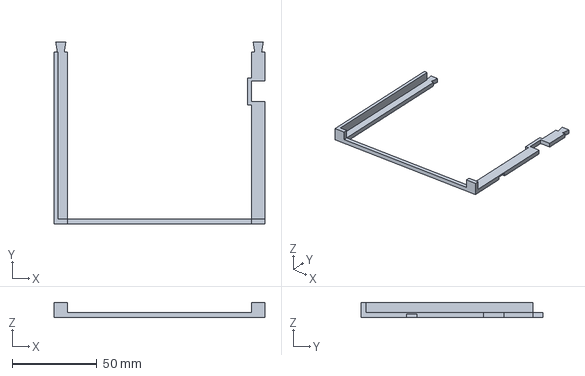
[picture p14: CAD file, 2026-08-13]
exports/individual/STEP/hdd_tray_front.step
124.3 x 107.2 x 9.00 mm

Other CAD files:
exports/individual/STEP/mid_frame.step
exports/individual/STEP/top_rear.step
exports/individual/STEP/left_side_front.step
exports/individual/STEP/right_side_rear.step
exports/assembly/NAS_Internal_Inspection.stl
exports/fit_tests/dovetail_fit_test.stl
exports/fit_tests/hdd_keeper_fit_test.3mf
exports/fit_tests/hdd_keeper_fit_test.stl
exports/fit_tests/hdd_keeper_retention_test.stl
exports/fit_tests/hdd_rail_fit_test.3mf
exports/fit_tests/hdd_rail_fit_test.stl
exports/fit_tests/panel_key_fit_test.stl
exports/individual/STEP/base_rear.step
exports/individual/STEP/cable_clip.step
exports/individual/STEP/foot.step
exports/individual/STEP/hdd_tray_rear.step
exports/individual/STEP/left_side_rear.step
exports/individual/STEP/rear_fan_guard.step
exports/individual/STEP/rear_panel.step
exports/individual/STEP/right_side_front.step
exports/individual/STEP/top_service_lid.step
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

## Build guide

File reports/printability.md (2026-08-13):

# Printability report

Configured printer: **Bambu Lab P1S**, physical build volume 256 x 256 x 256 mm.
Validated usable envelope: **250.00 × 250.00 × 250.00 mm** (3.0 mm XY margin per edge; explicit 250 mm usable-Z limit).

Every row is a hard build gate. Production geometry remains modular; no parts were merged for the larger bed.
PRINTED_PART_ASSEMBLY_IDENTITY summary: **31/31 PASS**.

| Part | STL bbox | MANIFOLD | PRINT BED | NON-ZERO VOLUME | Regions | Triangles | Min triangle area | Orientation | Supports |
|---|---|:---:|:---:|:---:|---:|---:|---:|---|---|
| `base_front` | 146.00 × 145.55 × 60.00 mm | PASS | PASS | PASS | 1/1 | 2912 | 0.126908 mm² | largest flat face on bed; detail side up | none |
| `base_rear` | 146.00 × 145.55 × 60.00 mm | PASS | PASS | PASS | 1/1 | 4984 | 0.076438 mm² | largest flat face on bed; detail side up | none |
| `foot` | 16.00 × 16.00 × 6.00 mm | PASS | PASS | PASS | 1/1 | 672 | 0.381389 mm² | largest flat face on bed; detail side up | none |
| `front_panel` | 143.20 × 168.40 × 2.80 mm | PASS | PASS | PASS | 1/1 | 1840 | 0.235548 mm² | exterior grille face on bed; interior face up | none |
| `rear_panel` | 143.20 × 168.40 × 2.80 mm | PASS | PASS | PASS | 1/1 | 4864 | 0.087057 mm² | exterior face on bed; grille and tongues upward | none |
| `rear_fan_guard` | 140.00 × 140.00 × 10.00 mm | PASS | PASS | PASS | 1/1 | 2236 | 0.053587 mm² | fan-side crossbar face on bed; spacer walls upward | none |
| `left_side_front` | 145.55 × 168.40 × 13.85 mm | PASS | PASS | PASS | 1/1 | 2336 | 0.126908 mm² | largest flat face on bed; detail side up | none |
| `left_side_rear` | 145.55 × 168.40 × 13.85 mm | PASS | PASS | PASS | 1/1 | 2272 | 0.201524 mm² | largest flat face on bed; detail side up | none |
| `right_side_front` | 145.55 × 168.40 × 13.85 mm | PASS | PASS | PASS | 1/1 | 2336 | 0.126908 mm² | largest flat face on bed; detail side up | none |
| `right_side_rear` | 145.55 × 168.40 × 13.85 mm | PASS | PASS | PASS | 1/1 | 2952 | 0.177967 mm² | largest flat face on bed; detail side up | none |
| `top_service_lid` | 146.00 × 145.55 × 6.80 mm | PASS | PASS | PASS | 1/1 | 3264 | 0.038662 mm² | largest flat face on bed; detail side up | none |
| `top_rear` | 146.00 × 145.55 × 6.80 mm | PASS | PASS | PASS | 1/1 | 3224 | 0.126908 mm² | largest flat face on bed; detail side up | none |
| `mid_frame` | 146.00 × 174.00 × 8.00 mm | PASS | PASS | PASS | 1/1 | 548 | 0.071106 mm² | broad face on bed | none |
| `mid_frame_right_spine` | 8.00 × 164.00 × 8.00 mm | PASS | PASS | PASS | 1/1 | 92 | 0.759999 mm² | largest flat face on bed; detail side up | none |
| `hdd_tray_front` | 124.30 × 107.25 × 9.00 mm | PASS | PASS | PASS | 1/1 | 148 | 1.200000 mm² | largest flat face on bed; detail side up | none |
| `hdd_tray_rear` | 124.30 × 101.25 × 9.00 mm | PASS | PASS | PASS | 1/1 | 110 | 0.080000 mm² | largest flat face on bed; detail side up | none |
| `hdd_keeper` | 8.00 × 16.00 × 9.00 mm | PASS | PASS | PASS | 1/1 | 76 | 0.001689 mm² | largest flat face on bed; detail side up | none |
| `pi_tray` | 128.00 × 95.00 × 8.00 mm | PASS | PASS | PASS | 1/1 | 184 | 1.619998 mm² | largest flat face on bed; detail side up | none |
| `usb_hub_mount` | 19.00 × 119.00 × 7.00 mm | PASS | PASS | PASS | 1/1 | 2220 | 0.013992 mm² | largest flat face on bed; detail side up | none |
| `cable_clip` | 12.80 × 10.00 × 15.20 mm | PASS | PASS | PASS | 1/1 | 384 | 0.157981 mm² | either broad XZ face on bed; cable opening visible from above | none |
| `dovetail_fit_test` | 154.00 × 66.00 × 6.50 mm | PASS | PASS | PASS | 10/10 | 2116 | 0.011250 mm² | flat coupon base on bed; labels and joint openings upward | none |
| `panel_key_fit_test` | 152.00 × 50.00 × 3.30 mm | PASS | PASS | PASS | 10/10 | 2056 | 0.011250 mm² | flat coupon base on bed; labels and joint openings upward | none |
| `hdd_rail_fit_test` | 124.30 × 32.00 × 9.00 mm | PASS | PASS | PASS | 1/1 | 52 | 7.200000 mm² | flat coupon base on bed; labels and joint openings upward | none |
| `hdd_keeper_fit_test` | 26.40 × 32.00 × 9.00 mm | PASS | PASS | PASS | 2/2 | 504 | 0.001690 mm² | flat coupon base on bed; labels and joint openings upward | none |
| `hdd_keeper_retention_test` | 122.20 × 32.00 × 9.00 mm | PASS | PASS | PASS | 10/10 | 4120 | 0.001690 mm² | flat coupon base on bed; labels and joint openings upward | none |

## Manufacturing assumptions

- 0.4 mm nozzle, 0.20 mm layers, PLA or PETG.
- Three to five perimeters; 20–30% gyroid/cubic infill for panels, 30–40% for keys and trays.
- Print broad exterior faces on the bed and interior ribs/grooves upward.
- No production part requires generated support in its preferred orientation.
- PETG is preferred for fan-adjacent pieces, dovetails, and long-term warm service.
- Add a brim only if needed; the largest production extent is 174 mm inside the 250 mm validated envelope.

## Hard-gate definitions

- **MANIFOLD PASS**: valid source BRep; expected connected regions; every raw STL edge used exactly twice with opposite winding; valid vertex links and stored normals; no sliver/degenerate or duplicate triangles; no triangle self-intersections; positive component orientations; independent VTK edge/region agreement.
- **PRINT BED PASS**: exported preferred-orientation STL bounds fit the conservative usable envelope and match source bounds.
- **NON-ZERO VOLUME PASS**: source, signed STL, VTK, and every connected component have positive volume; STL volume matches the source.
- **PRINTED_PART_ASSEMBLY_IDENTITY PASS**: the actual exported production STL is reopened and matches every placed printed instance using only a determinant-+1 rigid rotation and translation. Any match that requires reflection, or any stale/different export, is a hard failure. Left/right side exports receive additional distinctness and handed-pair checks.

## Automated results

- **PASS** — Individual STL inventory: Expected 20 STL file(s); found 20.
- **PASS** — MANIFOLD: base_front: 2912 triangles, 1 raw/1 VTK region(s); boundary 0, non-manifold 0, winding 0, vertex-link 0, sliver/degenerate 0, duplicate 0, normal 0, self-intersection 0; minimum triangle area 0.126908 mm²; source BRep valid (0 degenerate edges).
- **PASS** — PRINT BED: base_front: STL 146.00 × 145.55 × 60.00 mm; validated usable envelope 250.00 × 250.00 × 250.00 mm; source/STL bounds match; orthogonal alternative YES.
- **PASS** — NON-ZERO VOLUME: base_front: Source 60069.908 mm³; signed STL 60070.393 mm³; VTK 60070.393 mm³; all 1 component volume(s) positive.
- **PASS** — SOURCE/EXPORT IDENTITY: base_front: Source 1 solid(s), STEP 1; source/STL volume matches, source/STEP volume matches.
- **PASS** — MANIFOLD: base_rear: 4984 triangles, 1 raw/1 VTK region(s); boundary 0, non-manifold 0, winding 0, vertex-link 0, sliver/degenerate 0, duplicate 0, normal 0, self-intersection 0; minimum triangle area 0.076438 mm²; source BRep valid (0 degenerate edges).
- **PASS** — PRINT BED: base_rear: STL 146.00 × 145.55 × 60.00 mm; validated usable envelope 250.00 × 250.00 × 250.00 mm; source/STL bounds match; orthogonal alternative YES.
- **PASS** — NON-ZERO VOLUME: base_rear: Source 59430.321 mm³; signed STL 59430.985 mm³; VTK 59430.985 mm³; all 1 component volume(s) positive.
- **PASS** — SOURCE/EXPORT IDENTITY: base_rear: Source 1 solid(s), STEP 1; source/STL volume matches, source/STEP volume matches.
- **PASS** — MANIFOLD: foot: 672 triangles, 1 raw/1 VTK region(s); boundary 0, non-manifold 0, winding 0, vertex-link 0, sliver/degenerate 0, duplicate 0, normal 0, self-intersection 0; minimum triangle area 0.381389 mm²; source BRep valid (0 degenerate edges).
- **PASS** — PRINT BED: foot: STL 16.00 × 16.00 × 6.00 mm; validated usable envelope 250.00 × 250.00 × 250.00 mm; source/STL bounds match; orthogonal alternative YES.
- **PASS** — NON-ZERO VOLUME: foot: Source 1151.896 mm³; signed STL 1150.823 mm³; VTK 1150.823 mm³; all 1 component volume(s) positive.
- **PASS** — SOURCE/EXPORT IDENTITY: foot: Source 1 solid(s), STEP 1; source/STL volume matches, source/STEP volume matches.
- **PASS** — MANIFOLD: front_panel: 1840 triangles, 1 raw/1 VTK region(s); boundary 0, non-manifold 0, winding 0, vertex-link 0, sliver/degenerate 0, duplicate 0, normal 0, self-intersection 0; minimum triangle area 0.235548 mm²; source BRep valid (0 degenerate edges).
- **PASS** — PRINT BED: front_panel: STL 143.20 × 168.40 × 2.80 mm; validated usable envelope 250.00 × 250.00 × 250.00 mm; source/STL bounds match; orthogonal alternative YES.
- **PASS** — NON-ZERO VOLUME: front_panel: Source 46208.734 mm³; signed STL 46223.722 mm³; VTK 46223.722 mm³; all 1 component volume(s) positive.
- **PASS** — SOURCE/EXPORT IDENTITY: front_panel: Source 1 solid(s), STEP 1; source/STL volume matches, source/STEP volume matches.
- **PASS** — MANIFOLD: rear_panel: 4864 triangles, 1 raw/1 VTK region(s); boundary 0, non-manifold 0, winding 0, vertex-link 0, sliver/degenerate 0, duplicate 0, normal 0, self-intersection 0; minimum triangle area 0.087057 mm²; source BRep valid (0 degenerate edges).
- **PASS** — PRINT BED: rear_panel: STL 143.20 × 168.40 × 2.80 mm; validated usable envelope 250.00 × 250.00 × 250.00 mm; source/STL bounds match; orthogonal alternative YES.
- **PASS** — NON-ZERO VOLUME: rear_panel: Source 30105.284 mm³; signed STL 30126.665 mm³; VTK 30126.665 mm³; all 1 component volume(s) positive.
- **PASS** — SOURCE/EXPORT IDENTITY: rear_panel: Source 1 solid(s), STEP 1; source/STL volume matches, source/STEP volume matches.
- **PASS** — MANIFOLD: rear_fan_guard: 2236 triangles, 1 raw/1 VTK region(s); boundary 0, non-manifold 0, winding 0, vertex-link 0, sliver/degenerate 0, duplicate 0, normal 0, self-intersection 0; minimum triangle area 0.053587 mm²; source BRep valid (0 degenerate edges).
- **PASS** — PRINT BED: rear_fan_guard: STL 140.00 × 140.00 × 10.00 mm; validated usable envelope 250.00 × 250.00 × 250.00 mm; source/STL bounds match; orthogonal alternative YES.
- **PASS** — NON-ZERO VOLUME: rear_fan_guard: Source 26476.402 mm³; signed STL 26475.425 mm³; VTK 26475.425 mm³; all 1 component volume(s) positive.
- **PASS** — SOURCE/EXPORT IDENTITY: rear_fan_guard: Source 1 solid(s), STEP 1; source/STL volume matches, source/STEP volume matches.
- **PASS** — MANIFOLD: left_side_front: 2336 triangles, 1 raw/1 VTK region(s); boundary 0, non-manifold 0, winding 0, vertex-link 0, sliver/degenerate 0, duplicate 0, normal 0, self-intersection 0; minimum triangle area 0.126908 mm²; source BRep valid (0 degenerate edges).
- **PASS** — PRINT BED: left_side_front: STL 145.55 × 168.40 × 13.85 mm; validated usable envelope 250.00 × 250.00 × 250.00 mm; source/STL bounds match; orthogonal alternative YES.
- **PASS** — NON-ZERO VOLUME: left_side_front: Source 64939.447 mm³; signed STL 64939.888 mm³; VTK 64939.888 mm³; all 1 component volume(s) positive.
- **PASS** — SOURCE/EXPORT IDENTITY: left_side_front: Source 1 solid(s), STEP 1; source/STL volume matches, source/STEP volume matches.
- **PASS** — MANIFOLD: left_side_rear: 2272 triangles, 1 raw/1 VTK region(s); boundary 0, non-manifold 0, winding 0, vertex-link 0, sliver/degenerate 0, duplicate 0, normal 0, self-intersection 0; minimum triangle area 0.201524 mm²; source BRep valid (0 degenerate edges).
- **PASS** — PRINT BED: left_side_rear: STL 145.55 × 168.40 × 13.85 mm; validated usable envelope 250.00 × 250.00 × 250.00 mm; source/STL bounds match; orthogonal alternative YES.
- **PASS** — NON-ZERO VOLUME: left_side_rear: Source 64141.047 mm³; signed STL 64141.488 mm³; VTK 64141.488 mm³; all 1 component volume(s) positive.
- **PASS** — SOURCE/EXPORT IDENTITY: left_side_rear: Source 1 solid(s), STEP 1; source/STL volume matches, source/STEP volume matches.
- **PASS** — MANIFOLD: right_side_front: 2336 triangles, 1 raw/1 VTK region(s); boundary 0, non-manifold 0, winding 0, vertex-link 0, sliver/degenerate 0, duplicate 0, normal 0, self-intersection 0; minimum triangle area 0.126908 mm²; source BRep valid (0 degenerate edges).
- **PASS** — PRINT BED: right_side_front: STL 145.55 × 168.40 × 13.85 mm; validated usable envelope 250.00 × 250.00 × 250.00 mm; source/STL bounds match; orthogonal alternative YES.
- **PASS** — NON-ZERO VOLUME: right_side_front: Source 64939.447 mm³; signed STL 64939.888 mm³; VTK 64939.888 mm³; all 1 component volume(s) positive.
- **PASS** — SOURCE/EXPORT IDENTITY: right_side_front: Source 1 solid(s), STEP 1; source/STL volume matches, source/STEP volume matches.
- **PASS** — MANIFOLD: right_side_rear: 2952 triangles, 1 raw/1 VTK region(s); boundary 0, non-manifold 0, winding 0, vertex-link 0, sliver/degenerate 0, duplicate 0, normal 0, self-intersection 0; minimum triangle area 0.177967 mm²; source BRep valid (0 degenerate edges).
- **PASS** — PRINT BED: right_side_rear: STL 145.55 × 168.40 × 13.85 mm; validated usable envelope 250.00 × 250.00 × 250.00 mm; source/STL bounds match; orthogonal alternative YES.
- **PASS** — NON-ZERO VOLUME: right_side_rear: Source 64090.204 mm³; signed STL 64090.692 mm³; VTK 64090.692 mm³; all 1 component volume(s) positive.
- **PASS** — SOURCE/EXPORT IDENTITY: right_side_rear: Source 1 solid(s), STEP 1; source/STL volume matches, source/STEP volume matches.
- **PASS** — MANIFOLD: top_service_lid: 3264 triangles, 1 raw/1 VTK region(s); boundary 0, non-manifold 0, winding 0, vertex-link 0, sliver/degenerate 0, duplicate 0, normal 0, self-intersection 0; minimum triangle area 0.038662 mm²; source BRep valid (0 degenerate edges).
- **PASS** — PRINT BED: top_service_lid: STL 146.00 × 145.55 × 6.80 mm; validated usable envelope 250.00 × 250.00 × 250.00 mm; source/STL bounds match; orthogonal alternative YES.
- **PASS** — NON-ZERO VOLUME: top_service_lid: Source 55597.935 mm³; signed STL 55598.632 mm³; VTK 55598.632 mm³; all 1 component volume(s) positive.
- **PASS** — SOURCE/EXPORT IDENTITY: top_service_lid: Source 1 solid(s), STEP 1; source/STL volume matches, source/STEP volume matches.
- **PASS** — MANIFOLD: top_rear: 3224 triangles, 1 raw/1 VTK region(s); boundary 0, non-manifold 0, winding 0, vertex-link 0, sliver/degenerate 0, duplicate 0, normal 0, self-intersection 0; minimum triangle area 0.126908 mm²; source BRep valid (0 degenerate edges).
- **PASS** — PRINT BED: top_rear: STL 146.00 × 145.55 × 6.80 mm; validated usable envelope 250.00 × 250.00 × 250.00 mm; source/STL bounds match; orthogonal alternative YES.
- **PASS** — NON-ZERO VOLUME: top_rear: Source 55858.087 mm³; signed STL 55858.748 mm³; VTK 55858.748 mm³; all 1 component volume(s) positive.
- **PASS** — SOURCE/EXPORT IDENTITY: top_rear: Source 1 solid(s), STEP 1; source/STL volume matches, source/STEP volume matches.
- **PASS** — MANIFOLD: mid_frame: 548 triangles, 1 raw/1 VTK region(s); boundary 0, non-manifold 0, winding 0, vertex-link 0, sliver/degenerate 0, duplicate 0, normal 0, self-intersection 0; minimum triangle area 0.071106 mm²; source BRep valid (0 degenerate edges).
- **PASS** — PRINT BED: mid_frame: STL 146.00 × 174.00 × 8.00 mm; validated usable envelope 250.00 × 250.00 × 250.00 mm; source/STL bounds match; orthogonal alternative YES.
- **PASS** — NON-ZERO VOLUME: mid_frame: Source 26165.120 mm³; signed STL 26165.120 mm³; VTK 26165.120 mm³; all 1 component volume(s) positive.
- **PASS** — SOURCE/EXPORT IDENTITY: mid_frame: Source 1 solid(s), STEP 1; source/STL volume matches, source/STEP volume matches.
- **PASS** — MANIFOLD: mid_frame_right_spine: 92 triangles, 1 raw/1 VTK region(s); boundary 0, non-manifold 0, winding 0, vertex-link 0, sliver/degenerate 0, duplicate 0, normal 0, self-intersection 0; minimum triangle area 0.759999 mm²; source BRep valid (0 degenerate edges).
- **PASS** — PRINT BED: mid_frame_right_spine: STL 8.00 × 164.00 × 8.00 mm; validated usable envelope 250.00 × 250.00 × 250.00 mm; source/STL bounds match; orthogonal alternative YES.
- **PASS** — NON-ZERO VOLUME: mid_frame_right_spine: Source 9565.760 mm³; signed STL 9565.760 mm³; VTK 9565.760 mm³; all 1 component volume(s) positive.
- **PASS** — SOURCE/EXPORT IDENTITY: mid_frame_right_spine: Source 1 solid(s), STEP 1; source/STL volume matches, source/STEP volume matches.
- **PASS** — MANIFOLD: hdd_tray_front: 148 triangles, 1 raw/1 VTK region(s); boundary 0, non-manifold 0, winding 0, vertex-link 0, sliver/degenerate 0, duplicate 0, normal 0, self-intersection 0; minimum triangle area 1.200000 mm²; source BRep valid (0 degenerate edges).
- **PASS** — PRINT BED: hdd_tray_front: STL 124.30 × 107.25 × 9.00 mm; validated usable envelope 250.00 × 250.00 × 250.00 mm; source/STL bounds match; orthogonal alternative YES.
- **PASS** — NON-ZERO VOLUME: hdd_tray_front: Source 7485.820 mm³; signed STL 7485.820 mm³; VTK 7485.820 mm³; all 1 component volume(s) positive.
- **PASS** — SOURCE/EXPORT IDENTITY: hdd_tray_front: Source 1 solid(s), STEP 1; source/STL volume matches, source/STEP volume matches.
- **PASS** — MANIFOLD: hdd_tray_rear: 110 triangles, 1 raw/1 VTK region(s); boundary 0, non-manifold 0, winding 0, vertex-link 0, sliver/degenerate 0, duplicate 0, normal 0, self-intersection 0; minimum triangle area 0.080000 mm²; source BRep valid (0 degenerate edges).
- **PASS** — PRINT BED: hdd_tray_rear: STL 124.30 × 101.25 × 9.00 mm; validated usable envelope 250.00 × 250.00 × 250.00 mm; source/STL bounds match; orthogonal alternative YES.
- **PASS** — NON-ZERO VOLUME: hdd_tray_rear: Source 7125.383 mm³; signed STL 7125.383 mm³; VTK 7125.383 mm³; all 1 component volume(s) positive.
- **PASS** — SOURCE/EXPORT IDENTITY: hdd_tray_rear: Source 1 solid(s), STEP 1; source/STL volume matches, source/STEP volume matches.
- **PASS** — MANIFOLD: hdd_keeper: 76 triangles, 1 raw/1 VTK region(s); boundary 0, non-manifold 0, winding 0, vertex-link 0, sliver/degenerate 0, duplicate 0, normal 0, self-intersection 0; minimum triangle area 0.001689 mm²; source BRep valid (0 degenerate edges).
- **PASS** — PRINT BED: hdd_keeper: STL 8.00 × 16.00 × 9.00 mm; validated usable envelope 250.00 × 250.00 × 250.00 mm; source/STL bounds match; orthogonal alternative YES.
- **PASS** — NON-ZERO VOLUME: hdd_keeper: Source 468.685 mm³; signed STL 468.685 mm³; VTK 468.685 mm³; all 1 component volume(s) positive.
- **PASS** — SOURCE/EXPORT IDENTITY: hdd_keeper: Source 1 solid(s), STEP 1; source/STL volume matches, source/STEP volume matches.
- **PASS** — MANIFOLD: pi_tray: 184 triangles, 1 raw/1 VTK region(s); boundary 0, non-manifold 0, winding 0, vertex-link 0, sliver/degenerate 0, duplicate 0, normal 0, self-intersection 0; minimum triangle area 1.619998 mm²; source BRep valid (0 degenerate edges).
- **PASS** — PRINT BED: pi_tray: STL 128.00 × 95.00 × 8.00 mm; validated usable envelope 250.00 × 250.00 × 250.00 mm; source/STL bounds match; orthogonal alternative YES.
- **PASS** — NON-ZERO VOLUME: pi_tray: Source 11835.840 mm³; signed STL 11835.840 mm³; VTK 11835.840 mm³; all 1 component volume(s) positive.
- **PASS** — SOURCE/EXPORT IDENTITY: pi_tray: Source 1 solid(s), STEP 1; source/STL volume matches, source/STEP volume matches.
- **PASS** — MANIFOLD: usb_hub_mount: 2220 triangles, 1 raw/1 VTK region(s); boundary 0, non-manifold 0, winding 0, vertex-link 0, sliver/degenerate 0, duplicate 0, normal 0, self-intersection 0; minimum triangle area 0.013992 mm²; source BRep valid (0 degenerate edges).
- **PASS** — PRINT BED: usb_hub_mount: STL 19.00 × 119.00 × 7.00 mm; validated usable envelope 250.00 × 250.00 × 250.00 mm; source/STL bounds match; orthogonal alternative YES.
- **PASS** — NON-ZERO VOLUME: usb_hub_mount: Source 4558.929 mm³; signed STL 4559.008 mm³; VTK 4559.008 mm³; all 1 component volume(s) positive.
- **PASS** — SOURCE/EXPORT IDENTITY: usb_hub_mount: Source 1 solid(s), STEP 1; source/STL volume matches, source/STEP volume matches.
- **PASS** — MANIFOLD: cable_clip: 384 triangles, 1 raw/1 VTK region(s); boundary 0, non-manifold 0, winding 0, vertex-link 0, sliver/degenerate 0, duplicate 0, normal 0, self-intersection 0; minimum triangle area 0.157981 mm²; source BRep valid (0 degenerate edges).
- **PASS** — PRINT BED: cable_clip: STL 12.80 × 10.00 × 15.20 mm; validated usable envelope 250.00 × 250.00 × 250.00 mm; source/STL bounds match; orthogonal alternative YES.
- **PASS** — NON-ZERO VOLUME: cable_clip: Source 1166.020 mm³; signed STL 1166.061 mm³; VTK 1166.061 mm³; all 1 component volume(s) positive.
- **PASS** — SOURCE/EXPORT IDENTITY: cable_clip: Source 1 solid(s), STEP 1; source/STL volume matches, source/STEP volume matches.
- **PASS** — PRINTED_PART_ASSEMBLY_IDENTITY: base_front [base_front]: Actual STL matches the placed source by a proper rigid transform det=+1 (+X, +Y, +Z), translation (0.000, -0.000, 0.000) mm; bidirectional surface error 0.0000 mm, volume delta 0.486 mm³.
- **PASS** — PRINTED_PART_ASSEMBLY_IDENTITY: base_rear [base_rear]: Actual STL matches the placed source by a proper rigid transform det=+1 (+X, +Y, +Z), translation (0.000, 145.550, 0.000) mm; bidirectional surface error 0.0000 mm, volume delta 0.664 mm³.
- **PASS** — PRINTED_PART_ASSEMBLY_IDENTITY: top_service_lid [top_service_lid]: Actual STL matches the placed source by a proper rigid transform det=+1 (-X, +Y, -Z), translation (146.000, -0.000, 174.000) mm; bidirectional surface error 0.0000 mm, volume delta 0.697 mm³.
- **PASS** — PRINTED_PART_ASSEMBLY_IDENTITY: top_rear [top_rear]: Actual STL matches the placed source by a proper rigid transform det=+1 (-X, +Y, -Z), translation (146.000, 145.550, 174.000) mm; bidirectional surface error 0.0000 mm, volume delta 0.662 mm³.
- **PASS** — PRINTED_PART_ASSEMBLY_IDENTITY: left_side_front [left_side_front]: Actual STL matches the placed source by a proper rigid transform det=+1 (+Z, +X, +Y), translation (-0.000, -0.000, 2.800) mm; bidirectional surface error 0.0000 mm, volume delta 0.441 mm³.
- **PASS** — PRINTED_PART_ASSEMBLY_IDENTITY: left_side_rear [left_side_rear]: Actual STL matches the placed source by a proper rigid transform det=+1 (+Z, +X, +Y), translation (-0.000, 145.550, 2.800) mm; bidirectional surface error 0.0000 mm, volume delta 0.440 mm³.
- **PASS** — PRINTED_PART_ASSEMBLY_IDENTITY: right_side_front [right_side_front]: Actual STL matches the placed source by a proper rigid transform det=+1 (-Z, -X, +Y), translation (146.000, 145.550, 2.800) mm; bidirectional surface error 0.0000 mm, volume delta 0.441 mm³.
- **PASS** — PRINTED_PART_ASSEMBLY_IDENTITY: right_side_rear [right_side_rear]: Actual STL matches the placed source by a proper rigid transform det=+1 (-Z, -X, +Y), translation (146.000, 291.100, 2.800) mm; bidirectional surface error 0.0000 mm, volume delta 0.488 mm³.
- **PASS** — PRINTED_PART_ASSEMBLY_IDENTITY: front_panel [front_panel]: Actual STL matches the placed source by a proper rigid transform det=+1 (+X, -Z, +Y), translation (1.400, 2.800, 2.800) mm; bidirectional surface error 0.0000 mm, volume delta 14.988 mm³.
- **PASS** — PRINTED_PART_ASSEMBLY_IDENTITY: rear_panel [rear_panel]: Actual STL matches the placed source by a proper rigid transform det=+1 (+X, -Z, +Y), translation (1.400, 291.100, 2.800) mm; bidirectional surface error 0.0000 mm, volume delta 21.381 mm³.
- **PASS** — PRINTED_PART_ASSEMBLY_IDENTITY: mid_frame [mid_frame]: Actual STL matches the placed source by a proper rigid transform det=+1 (+X, -Z, +Y), translation (0.000, 149.550, 0.000) mm; bidirectional surface error 0.0000 mm, volume delta 0.000 mm³.
- **PASS** — PRINTED_PART_ASSEMBLY_IDENTITY: mid_frame_right_spine [mid_frame_right_spine]: Actual STL matches the placed source by a proper rigid transform det=+1 (+X, -Z, +Y), translation (138.000, 149.550, 5.000) mm; bidirectional surface error 0.0000 mm, volume delta 0.000 mm³.
- **PASS** — PRINTED_PART_ASSEMBLY_IDENTITY: hdd_tray_lower_front [hdd_tray_front]: Actual STL matches the placed source by a proper rigid transform det=+1 (+X, +Y, +Z), translation (10.850, 30.050, 10.000) mm; bidirectional surface error 0.0000 mm, volume delta 0.000 mm³.
- **PASS** — PRINTED_PART_ASSEMBLY_IDENTITY: hdd_tray_lower_rear [hdd_tray_rear]: Actual STL matches the placed source by a proper rigid transform det=+1 (+X, +Y, +Z), translation (10.850, 131.300, 10.000) mm; bidirectional surface error 0.0000 mm, volume delta 0.000 mm³.
- **PASS** — PRINTED_PART_ASSEMBLY_IDENTITY: hdd_keeper_lower [hdd_keeper]: Actual STL matches the placed source by a proper rigid transform det=+1 (+X, +Y, +Z), translation (127.150, 100.200, 10.000) mm; bidirectional surface error 0.0000 mm, volume delta 0.000 mm³.
- **PASS** — PRINTED_PART_ASSEMBLY_IDENTITY: hdd_tray_upper_front [hdd_tray_front]: Actual STL matches the placed source by a proper rigid transform det=+1 (+X, +Y, +Z), translation (10.850, 30.050, 60.000) mm; bidirectional surface error 0.0000 mm, volume delta 0.000 mm³.
- **PASS** — PRINTED_PART_ASSEMBLY_IDENTITY: hdd_tray_upper_rear [hdd_tray_rear]: Actual STL matches the placed source by a proper rigid transform det=+1 (+X, +Y, +Z), translation (10.850, 131.300, 60.000) mm; bidirectional surface error 0.0000 mm, volume delta 0.000 mm³.
- **PASS** — PRINTED_PART_ASSEMBLY_IDENTITY: hdd_keeper_upper [hdd_keeper]: Actual STL matches the placed source by a proper rigid transform det=+1 (+X, +Y, +Z), translation (127.150, 100.200, 60.000) mm; bidirectional surface error 0.0000 mm, volume delta 0.000 mm³.
- **PASS** — PRINTED_PART_ASSEMBLY_IDENTITY: pi_tray [pi_tray]: Actual STL matches the placed source by a proper rigid transform det=+1 (+X, +Y, +Z), translation (9.000, 42.800, 110.000) mm; bidirectional surface error 0.0000 mm, volume delta 0.000 mm³.
- **PASS** — PRINTED_PART_ASSEMBLY_IDENTITY: usb_hub_mount [usb_hub_mount]: Actual STL matches the placed source by a proper rigid transform det=+1 (-Z, -X, +Y), translation (143.200, 262.800, 43.500) mm; bidirectional surface error 0.0000 mm, volume delta 0.079 mm³.
- **PASS** — PRINTED_PART_ASSEMBLY_IDENTITY: rear_fan_guard [rear_fan_guard]: Actual STL matches the placed source by a proper rigid transform det=+1 (-X, -Z, -Y), translation (143.000, 301.100, 169.200) mm; bidirectional surface error 0.0000 mm, volume delta 0.978 mm³.
- **PASS** — PRINTED_PART_ASSEMBLY_IDENTITY: foot_1 [foot]: Actual STL matches the placed source by a proper rigid transform det=+1 (+X, +Y, +Z), translation (6.000, 6.000, -6.000) mm; bidirectional surface error 0.0000 mm, volume delta 1.074 mm³.
- **PASS** — PRINTED_PART_ASSEMBLY_IDENTITY: foot_2 [foot]: Actual STL matches the placed source by a proper rigid transform det=+1 (+X, +Y, +Z), translation (124.000, 6.000, -6.000) mm; bidirectional surface error 0.0000 mm, volume delta 1.074 mm³.
- **PASS** — PRINTED_PART_ASSEMBLY_IDENTITY: foot_3 [foot]: Actual STL matches the placed source by a proper rigid transform det=+1 (+X, +Y, +Z), translation (6.000, 269.100, -6.000) mm; bidirectional surface error 0.0000 mm, volume delta 1.074 mm³.
- **PASS** — PRINTED_PART_ASSEMBLY_IDENTITY: foot_4 [foot]: Actual STL matches the placed source by a proper rigid transform det=+1 (+X, +Y, +Z), translation (124.000, 269.100, -6.000) mm; bidirectional surface error 0.0000 mm, volume delta 1.074 mm³.
- **PASS** — PRINTED_PART_ASSEMBLY_IDENTITY: cable_clip_1 [cable_clip]: Actual STL matches the placed source by a proper rigid transform det=+1 (+X, +Y, +Z), translation (13.600, 262.300, 2.800) mm; bidirectional surface error 0.0000 mm, volume delta 0.041 mm³.
- **PASS** — PRINTED_PART_ASSEMBLY_IDENTITY: cable_clip_2 [cable_clip]: Actual STL matches the placed source by a proper rigid transform det=+1 (+X, +Y, +Z), translation (119.600, 262.300, 2.800) mm; bidirectional surface error 0.0000 mm, volume delta 0.041 mm³.
- **PASS** — PRINTED_PART_ASSEMBLY_IDENTITY: front side exports distinct: Left and right exports are physically distinct; they are not proper-rigid copies.
- **PASS** — PRINTED_PART_ASSEMBLY_IDENTITY: rear side exports distinct: Left and right exports are physically distinct; they are not proper-rigid copies.
- **PASS** — PRINTED_PART_ASSEMBLY_IDENTITY: front side physical mirror pair: The exported front modules are the intended longitudinal physical mirror pair (surface error 0.0000 mm).
- **PASS** — PRINTED_PART_ASSEMBLY_IDENTITY: rear side handed counterparts: Both physically distinct rear exports independently reach their placed sides by proper transforms; exact mirror equality is intentionally not required because only the right rear carries USB-hub mounting apertures.
- **PASS** — MANIFOLD: dovetail_fit_test: 2116 triangles, 10 raw/10 VTK region(s); boundary 0, non-manifold 0, winding 0, vertex-link 0, sliver/degenerate 0, duplicate 0, normal 0, self-intersection 0; minimum triangle area 0.011250 mm²; source BRep valid (0 degenerate edges).
- **PASS** — PRINT BED: dovetail_fit_test: STL 154.00 × 66.00 × 6.50 mm; validated usable envelope 250.00 × 250.00 × 250.00 mm; source/STL bounds match; orthogonal alternative YES.
- **PASS** — NON-ZERO VOLUME: dovetail_fit_test: Source 19392.067 mm³; signed STL 19392.067 mm³; VTK 19392.067 mm³; all 10 component volume(s) positive.
- **PASS** — SOURCE/EXPORT IDENTITY: dovetail_fit_test: Source 10 solid(s), STEP 10; source/STL volume matches, source/STEP volume matches.
- **PASS** — MANIFOLD: panel_key_fit_test: 2056 triangles, 10 raw/10 VTK region(s); boundary 0, non-manifold 0, winding 0, vertex-link 0, sliver/degenerate 0, duplicate 0, normal 0, self-intersection 0; minimum triangle area 0.011250 mm²; source BRep valid (0 degenerate edges).
- **PASS** — PRINT BED: panel_key_fit_test: STL 152.00 × 50.00 × 3.30 mm; validated usable envelope 250.00 × 250.00 × 250.00 mm; source/STL bounds match; orthogonal alternative YES.
- **PASS** — NON-ZERO VOLUME: panel_key_fit_test: Source 10296.973 mm³; signed STL 10296.973 mm³; VTK 10296.973 mm³; all 10 component volume(s) positive.
- **PASS** — SOURCE/EXPORT IDENTITY: panel_key_fit_test: Source 10 solid(s), STEP 10; source/STL volume matches, source/STEP volume matches.
- **PASS** — MANIFOLD: hdd_rail_fit_test: 52 triangles, 1 raw/1 VTK region(s); boundary 0, non-manifold 0, winding 0, vertex-link 0, sliver/degenerate 0, duplicate 0, normal 0, self-intersection 0; minimum triangle area 7.200000 mm²; source BRep valid (0 degenerate edges).
- **PASS** — PRINT BED: hdd_rail_fit_test: STL 124.30 × 32.00 × 9.00 mm; validated usable envelope 250.00 × 250.00 × 250.00 mm; source/STL bounds match; orthogonal alternative YES.
- **PASS** — NON-ZERO VOLUME: hdd_rail_fit_test: Source 3216.300 mm³; signed STL 3216.300 mm³; VTK 3216.300 mm³; all 1 component volume(s) positive.
- **PASS** — SOURCE/EXPORT IDENTITY: hdd_rail_fit_test: Source 1 solid(s), STEP 1; source/STL volume matches, source/STEP volume matches.
- **PASS** — MANIFOLD: hdd_keeper_fit_test: 504 triangles, 2 raw/2 VTK region(s); boundary 0, non-manifold 0, winding 0, vertex-link 0, sliver/degenerate 0, duplicate 0, normal 0, self-intersection 0; minimum triangle area 0.001690 mm²; source BRep valid (0 degenerate edges).
- **PASS** — PRINT BED: hdd_keeper_fit_test: STL 26.40 × 32.00 × 9.00 mm; validated usable envelope 250.00 × 250.00 × 250.00 mm; source/STL bounds match; orthogonal alternative YES.
- **PASS** — NON-ZERO VOLUME: hdd_keeper_fit_test: Source 1069.765 mm³; signed STL 1069.765 mm³; VTK 1069.765 mm³; all 2 component volume(s) positive.
- **PASS** — SOURCE/EXPORT IDENTITY: hdd_keeper_fit_test: Source 2 solid(s), STEP 2; source/STL volume matches, source/STEP volume matches.
- **PASS** — MANIFOLD: hdd_keeper_retention_test: 4120 triangles, 10 raw/10 VTK region(s); boundary 0, non-manifold 0, winding 0, vertex-link 0, sliver/degenerate 0, duplicate 0, normal 0, self-intersection 0; minimum triangle area 0.001690 mm²; source BRep valid (0 degenerate edges).
- **PASS** — PRINT BED: hdd_keeper_retention_test: STL 122.20 × 32.00 × 9.00 mm; validated usable envelope 250.00 × 250.00 × 250.00 mm; source/STL bounds match; orthogonal alternative YES.
- **PASS** — NON-ZERO VOLUME: hdd_keeper_retention_test: Source 5305.564 mm³; signed STL 5305.563 mm³; VTK 5305.563 mm³; all 10 component volume(s) positive.
- **PASS** — SOURCE/EXPORT IDENTITY: hdd_keeper_retention_test: Source 10 solid(s), STEP 10; source/STL volume matches, source/STEP volume matches.
- **PASS** — STEP artifact: NAS_Assembly: Reopened with 42 valid solid(s), volume 3170603.32 mm³; expected 42 solid(s) and 3170603.32 mm³.
- **PASS** — STEP artifact: NAS_Exploded: Reopened with 42 valid solid(s), volume 3170603.32 mm³; expected 42 solid(s) and 3170603.32 mm³.
- **PASS** — STEP artifact: NAS_Internal_Inspection: Reopened with 37 valid solid(s), volume 2883908.91 mm³; expected 37 solid(s) and 2883908.91 mm³.
- **PASS** — STEP artifact: NAS_Clearance_Check: Reopened with 81 valid solid(s), volume 7940244.54 mm³; expected 81 solid(s) and 7940244.54 mm³.

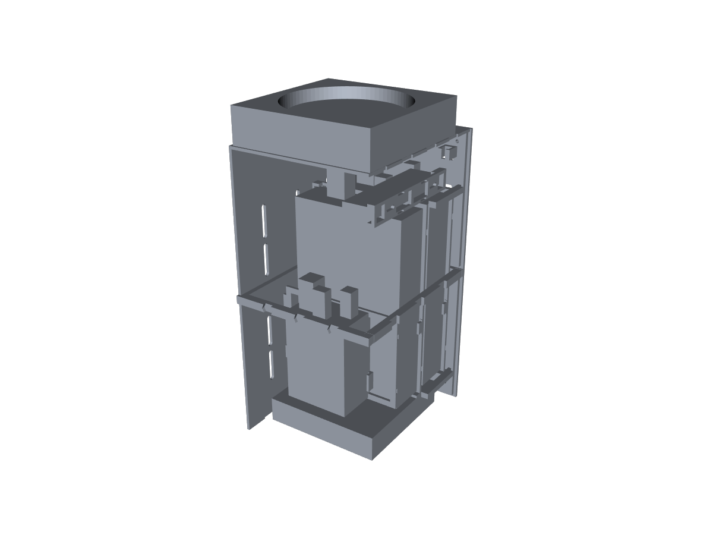
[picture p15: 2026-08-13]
exports/assembly/NAS_Internal_Inspection_preview.png

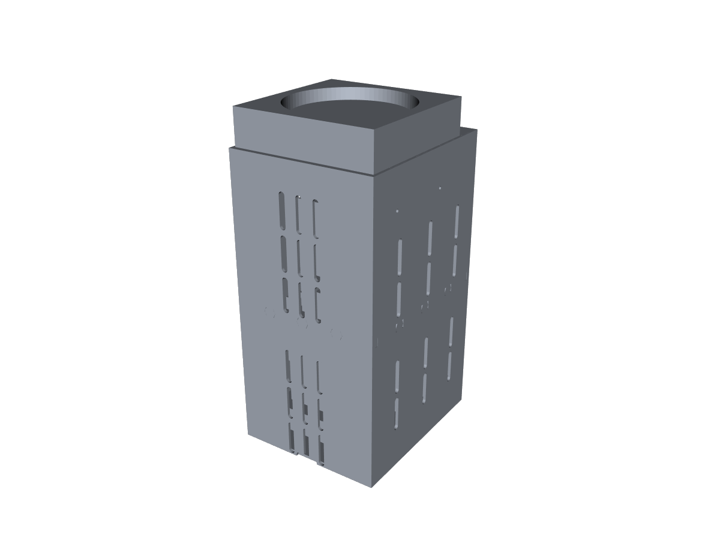
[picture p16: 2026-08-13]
exports/assembly/NAS_Assembly_preview.png

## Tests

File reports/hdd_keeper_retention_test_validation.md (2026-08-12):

# HDD keeper retention test validation

This focused build does not regenerate or modify enclosure artifacts.

## Test matrix

| Label | Clearance per side | Friction-bead projection | Net positive interference |
|---:|---:|---:|---:|
| 00 | 0.00 mm | 0.10 mm | 0.10 mm |
| 05 | 0.05 mm | 0.20 mm | 0.10 mm |
| 10 | 0.10 mm | 0.30 mm | 0.10 mm |
| 15 | 0.15 mm | 0.40 mm | 0.10 mm |
| 20 | 0.20 mm | 0.50 mm | 0.10 mm |

The broad rounded bead is fused into the keeper body; there are no thin snap tabs. Each variant has the same nominal 0.10 mm positive preload after its opposite flat face shifts against the socket wall.

## Export validation

- Exported bounds: **122.20 x 32.00 x 9.00 mm**
- Expected connected solids: **10**
- **PASS** — MANIFOLD: hdd_keeper_retention_test: 4120 triangles, 10 raw/10 VTK region(s); boundary 0, non-manifold 0, winding 0, vertex-link 0, sliver/degenerate 0, duplicate 0, normal 0, self-intersection 0; minimum triangle area 0.001690 mm²; source BRep valid (0 degenerate edges).
- **PASS** — PRINT BED: hdd_keeper_retention_test: STL 122.20 × 32.00 × 9.00 mm; validated usable envelope 250.00 × 250.00 × 250.00 mm; source/STL bounds match; orthogonal alternative YES.
- **PASS** — NON-ZERO VOLUME: hdd_keeper_retention_test: Source 5305.564 mm³; signed STL 5305.563 mm³; VTK 5305.563 mm³; all 10 component volume(s) positive.
- **PASS** — SOURCE/EXPORT IDENTITY: hdd_keeper_retention_test: Source 10 solid(s), STEP 10; source/STL volume matches, source/STEP volume matches.

## Physical test

1. Print the exported STL flat with labels and keeper guides upward, using the final filament/profile.
2. Match each loose keeper to the socket with the same 00/05/10/15/20 label.
3. Face the guide toward the open/outboard side and press vertically until both shoulders seat.
4. After cooling, invert and lightly shake; reject any variant that drops or rattles noticeably.
5. Confirm the keeper can still be removed by hand without tools or damage.

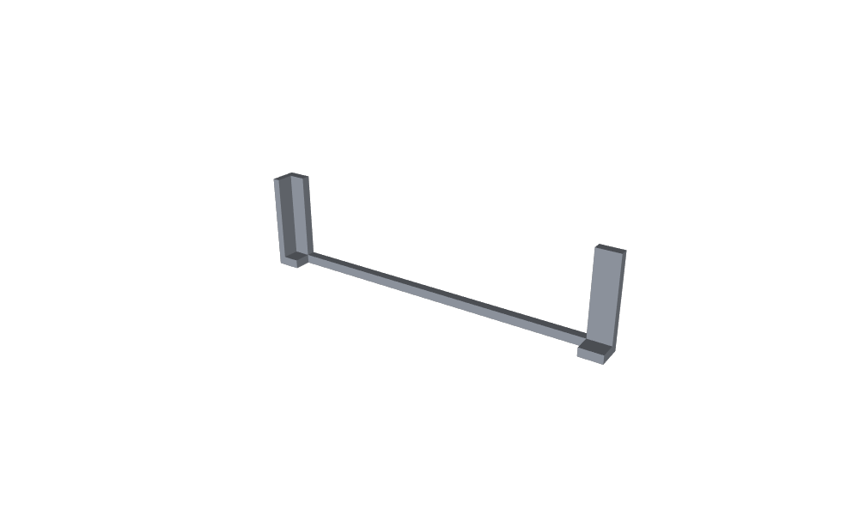
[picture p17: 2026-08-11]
exports/fit_tests/hdd_rail_fit_test_preview.png

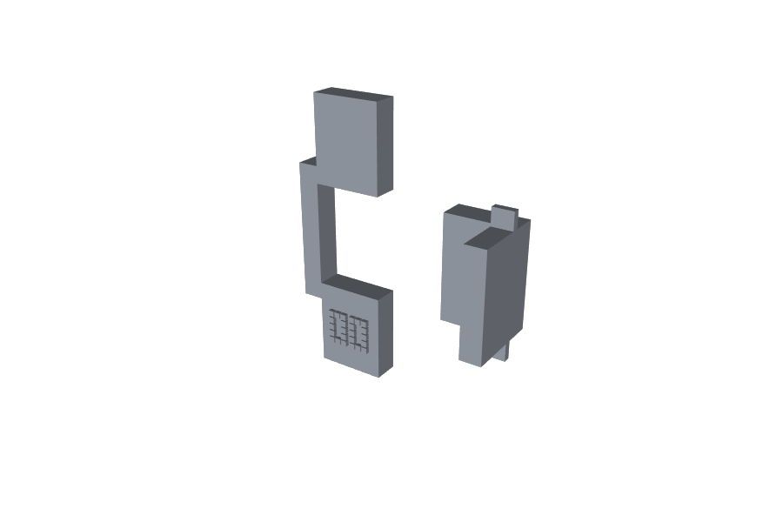
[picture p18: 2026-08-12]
exports/fit_tests/hdd_keeper_fit_test_preview.png

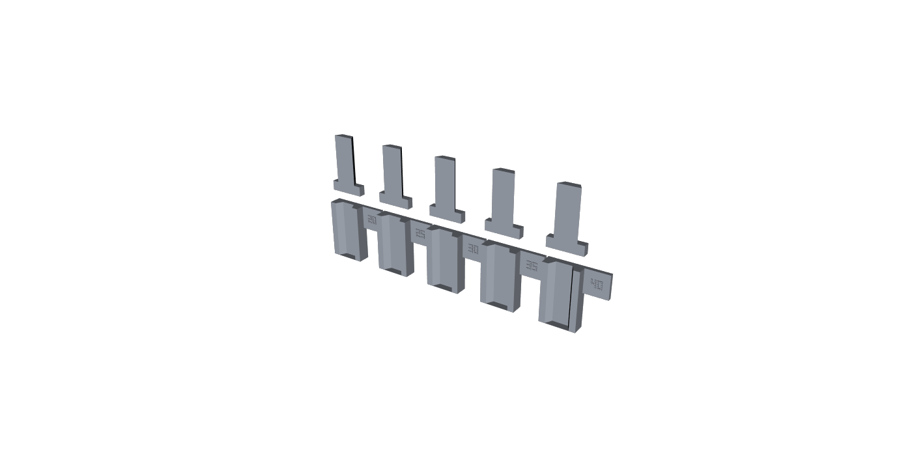
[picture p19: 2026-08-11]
exports/fit_tests/dovetail_fit_test_preview.png

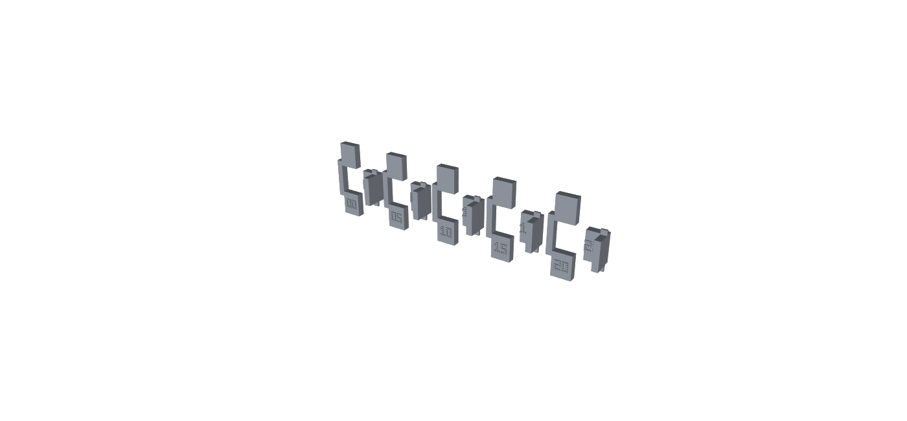
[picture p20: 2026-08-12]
exports/fit_tests/hdd_keeper_retention_test_preview.png

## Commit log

2026-08-11 Gehäuse erstellt mit Tests
    [NAS_Assembly.stl, NAS_Exploded.stl, NAS_Internal_Inspection.step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]
2026-08-12 updated to perfect fit
    [NAS_Assembly.stl, NAS_Exploded.stl, NAS_Internal_Inspection.step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]
2026-08-13 fixed the fans
    [NAS_Assembly.stl, NAS_Exploded.stl, NAS_Internal_Inspection.step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]
2026-08-13 fixed rear fan
    [NAS_Assembly.stl, NAS_Exploded.stl, NAS_Internal_Inspection.step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]
2026-08-13 fixed right side
    [NAS_Assembly.stl, NAS_Exploded.stl, NAS_Internal_Inspection.step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]
